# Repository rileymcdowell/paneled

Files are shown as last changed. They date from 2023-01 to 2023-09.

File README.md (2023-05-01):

# The PaneLED Project

PaneLED is an open source hardware, firmware, and software system for managing 
collections of independent RGBW light strips over WiFi via a simple interface.

Features include autodiscovery of new panels via UPnP, group administration 
of like-colored panels, and over-wifi firmware updates.

### Construction Guide 
---

1. [Bill of Materials](/instructions/00_bill_of_materials/README.md)
1. [Circuit Board](/instructions/10_circuit_board/README.md)
1. [Electronics Enclosure](/instructions/20_electronics_enclosure/README.md)
1. [Panel Assembly](/instructions/30_panel_assembly/README.md)
1. [Hanging Hardware](/instructions/40_hanging_hardware/README.md)
1. [Mount Options](/instructions/50_mount_options/README.md)

### Software Development Guide
---

Begin by installing docker and npm

In one terminal, run the following commands to start up the backend.

```bash
./build.sh # Build the docker containers for this project
./up.sh # Start the containers for this project
```

In another terminal, run the following commands to start up the frontend.

```bash
cd frontend
npm install
./start-frontend.sh
```

### License
---

All contents within this repository are released under one of two different licenses. The licenses were chosen to ensure that improvements to this design are shared with the open source community.

All source code is released under the GNU GPL V3.0 license. All remaining resources are released under the CC BY-SA 4.0 license. Below is a mapping of resources to the license
for those resources. 

* GNU GPL V3.0 
    * server source code
    * frontend source code
    * firmware source code
    * docker build and deployment utilities
* CC BY-SA 4.0
    * Enclosure model (lid + box)
    * PCB design
    * Panel frame design
    * Build instructions

The text of both licenses are included in the root of this repository.

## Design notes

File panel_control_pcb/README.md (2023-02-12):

This directory contains a `.f3z` archive that can be loaded into 
Autodesk's Fusion360 to get a complete copy of the PCB design documents
including schematic, board layout, and 3D rendering.

Autodesk offers a free, personal, non-commercial-use version of 
Fusion360, so if that sounds like you and you don't have a philosophical 
objection to the use of nonfree Fusion360 and/or Autodesk just make
an account, download it, and open the `.f3z` file to get access to
everything.

---

In addition, I've copied the individual schematic and board layout files
here for anyone who wishes to use alternative tooling or just get a 
copy of the exported board to order from a PCB prototyping house.

* Board (Gerber) files - `PCB v14_2023-02-12.zip`
* Schematic - `Schematic v10.pdf`

Below are a couple of screenshots you can use to confirm that your tools
have correctly read the source files.

The board layout should look like this:

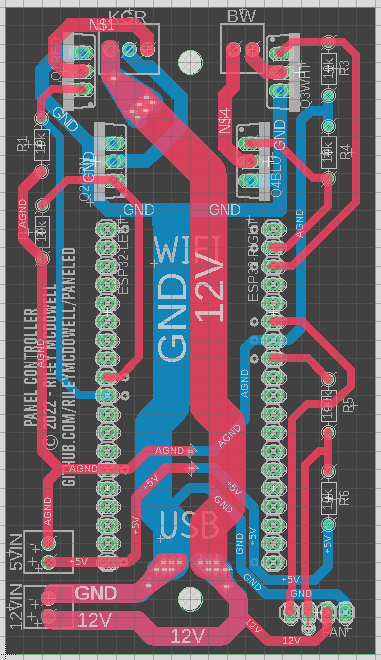
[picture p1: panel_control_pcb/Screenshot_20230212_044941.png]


And the schematic like this:

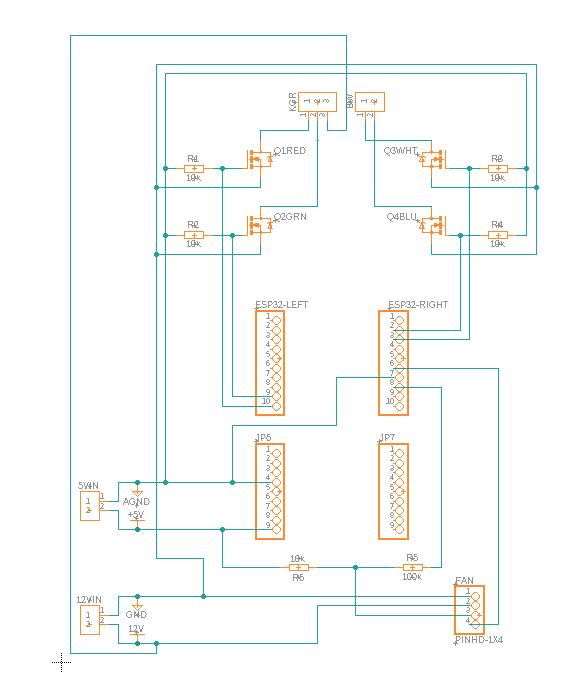
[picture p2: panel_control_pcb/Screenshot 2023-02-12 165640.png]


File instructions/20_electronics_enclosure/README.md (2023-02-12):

# Assembling the Electronics Enclosure

## 3D Printing 

### The Box

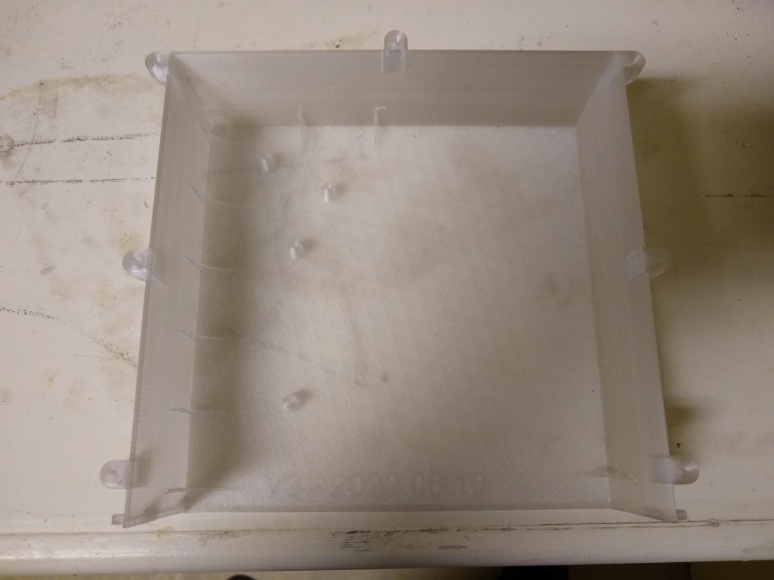
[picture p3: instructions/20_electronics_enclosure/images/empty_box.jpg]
empty box


First, you want to print the box. It's fairly large, about 210mm on each side. It will fit on the build plate
on a 220mm x 220mm 3D printer. I tried a few ways, here's what worked consistently for me:

* Print in Hatchbox brand transparent PETG with an 80&deg; bed and 235&deg; nozzle.
* Scale the model to 101% before printing to allow for thermal contraction to the correct final size after printing.
* Print with part cooling fan speed low, but non zero. I used 25% speed.
* Print on a glass bed inside an enclosure. This limits warping, delamination, and/or loss of bed adhesion.
* Use a 0.6mm diameter nozzle at 0.2mm layer height. With these settings, the box takes about 18 hours to complete.
* Print with an 8mm brim to keep the sharp corners from lifting.
* Use a generous coat of purple glue stick on the bed to ensure good bed adhesion.
* Use a wall line count of 4. This keeps the screw holes surrounded by several lines of solid plastic to tap into.
* Print the initial layer at 15mm/s. I found this helped ensure good adhesion.
* Use 20% infill (triangles). This is of minor importance as most of the box will print solid with these settings.

---
### The Lid

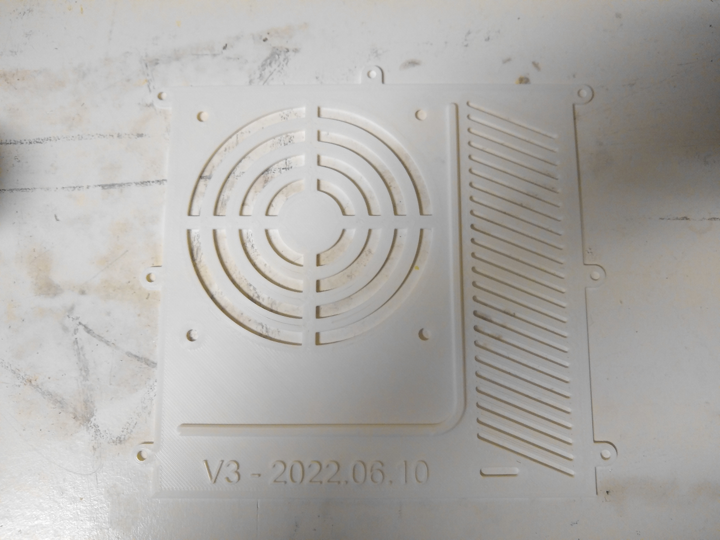
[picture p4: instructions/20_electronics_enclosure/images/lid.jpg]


After you get the box right, print a lid to match. It's roughly the same dimensions, but relatively flat so it will
be less affected by warping due to close proximity to a heated bed. This was easier to get right than the
PETG box, and I found only a subset of those settings was required to get a good result.

* Print in Hatchbox brand white ABS with a 100&deg; bed and 225&deg; nozzle.
* Scale the model to 101% before printing to allow for thermal contraction to the correct final size after printing.
* Print with part cooling fan low but non zero. I used 25% speed.
* Print on a glass bed.
* Print with an 8mm brim to keep the sharp corners from lifting.
* Use a 0.6mm diameter nozzle at 0.2mm layer height. With these settings, each lid takes about 8 hours to complete.
* Use 5 line thick walls - this improves printing speed due to more efficient print head movements.
* Print the initial layer at 15mm/s. I found this helped ensure good adhesion.
* Use 20% infill (triangles). This is of minor importance as most of the box will print solid with these settings.

---
## Tapping Threads

The holes in the box are sized to have threads tapped into them. Due to the depth of the box, it is highly 
recommended to use a small "T" handle tap wrench as shown. I found my double-end adjustable style
hit the walls of the box as I tapped the threads, so I needed to switch to the "T" handle style.

The 7 outer holes of the box are sized to be tapped to M3.5 size. 

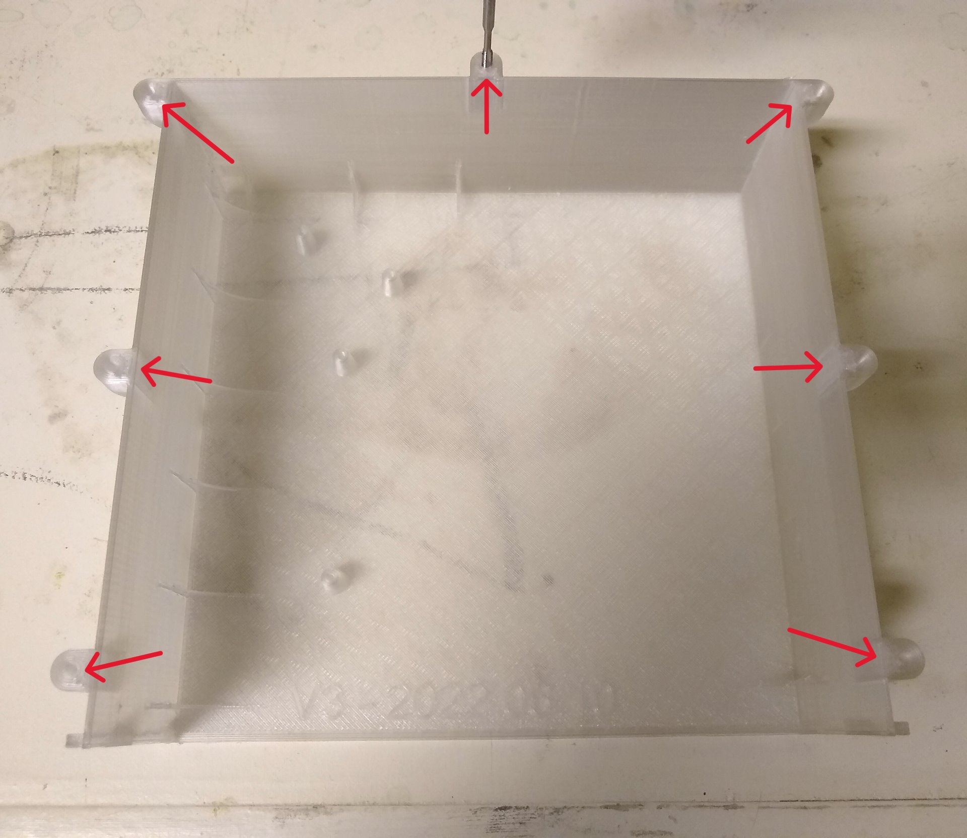
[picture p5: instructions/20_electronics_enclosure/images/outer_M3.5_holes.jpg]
Location of M3.5 holes to tap


The 4 inner holes of the box are sized to be tapped to the slighly smaller M3 size. This
seems to be a common size for PCB mount holes.

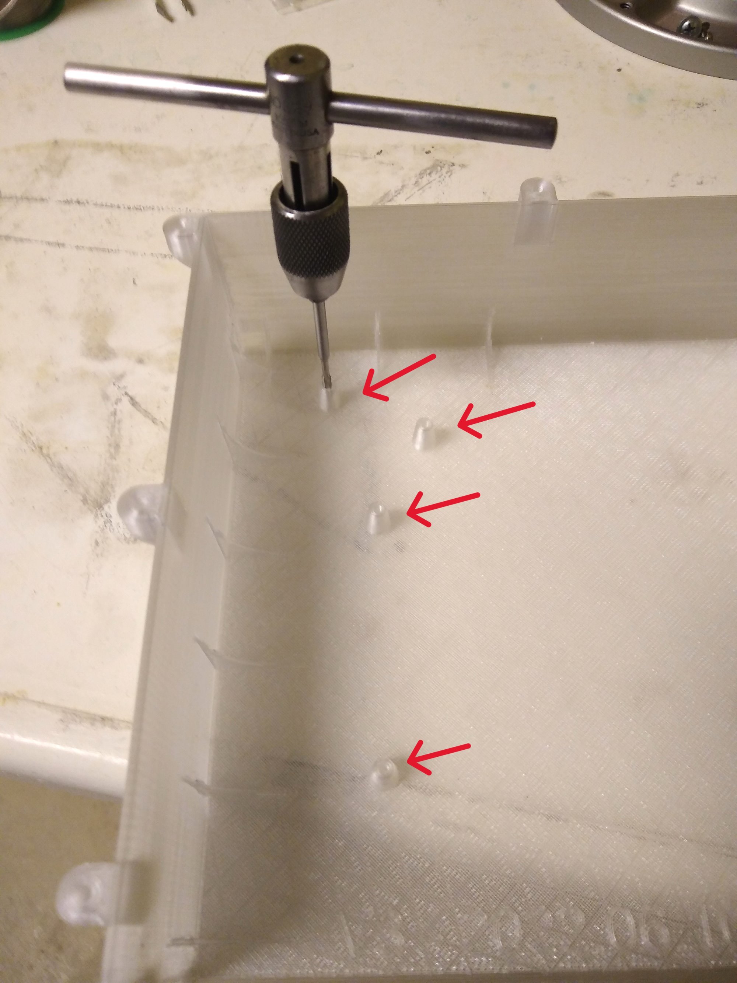
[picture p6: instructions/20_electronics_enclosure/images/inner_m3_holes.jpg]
Location of M3 holes to tap


---

## Assembling the Internals

### Step 0

Verify the power supply is set to the correct voltage for your local mains.

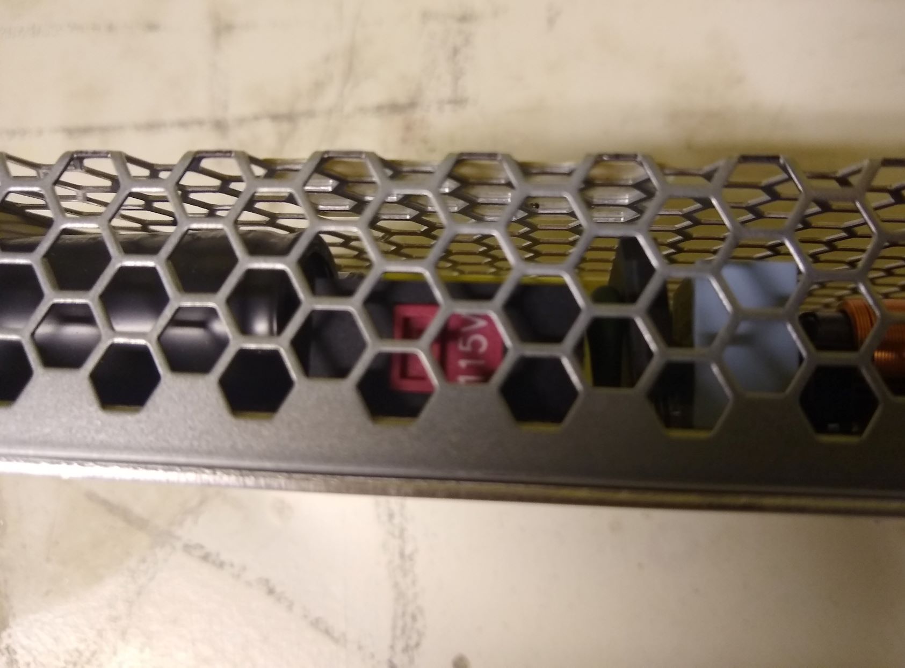
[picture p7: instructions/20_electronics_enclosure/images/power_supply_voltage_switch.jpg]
power supply voltage switch


### Step 1
Begin by putting the 12V Power supply into the box. Attach it with three M3 screws on the right side of the box.

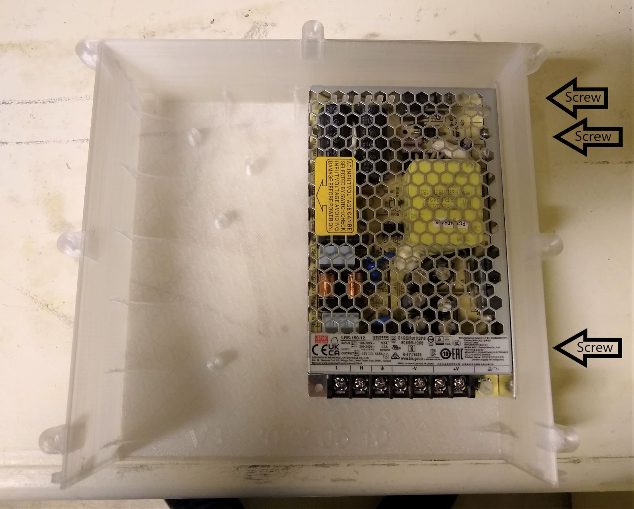
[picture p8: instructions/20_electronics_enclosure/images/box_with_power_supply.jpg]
box with power supply


### Step 2
Next, strip both ends of a pair of wires. I used the following:

* Red / Positive - 21cm (8.25in) of 24AWG stranded wire
* Black / Negative - 20cm (8in) of 24AWG stranded wire

For each wire, strip one end back about 8mm and fix it into the screw terminals 
on the power supply, red should go to `+V` and black to `-V`. Strip the other end about 4mm and leave them for the next step.
It should look like this.

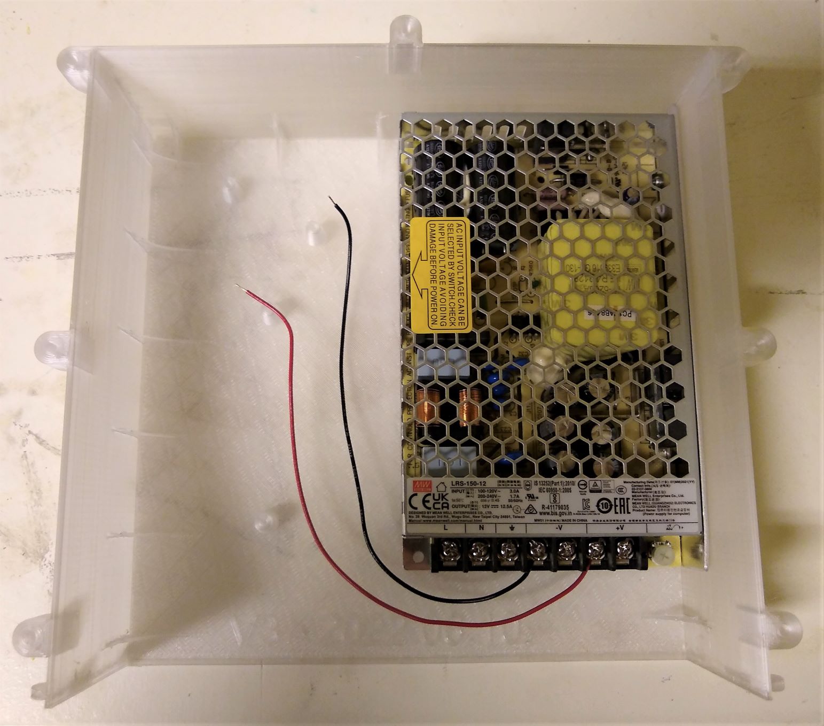
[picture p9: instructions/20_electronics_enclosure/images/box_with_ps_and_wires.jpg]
box with power supply and wires


### Step 3
Next we need to adjust a buck converter to buck down to 5V from the factory set voltage. 
Use a voltage source like a bench power supply or 9V battery to produce a voltage 
somewhat greater than the 5V required by the ESP32 dev board. Connect it to the 
`+in` and `-in` solder terminals on the buck converter. Then use a digital 
multimeter to read the voltage on the output terminals. Turn counterclockwise 
until the voltage is bucked down to 5V. **Note**: many buck converters come 
pre-set to a voltage many times higher than 5V. You will need to apply 
a **large number** of counterclockwise turns before you will see a noticable 
bucking effect on voltage.

I suggest adjusting to within 5.00&#xb1;0.05V.

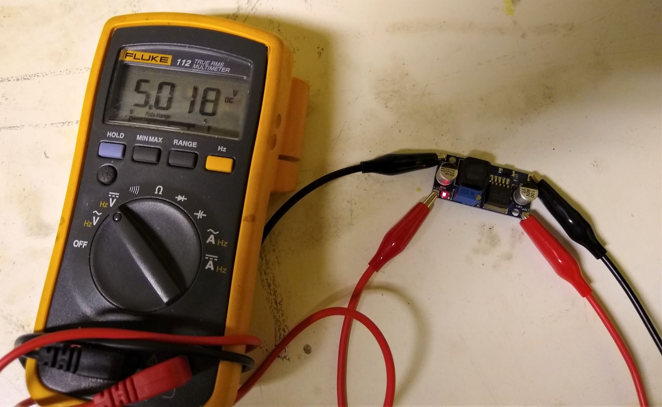
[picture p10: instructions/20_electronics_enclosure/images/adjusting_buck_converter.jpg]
adjusing buck converter


### Step 4
Solder the `+in` terminal of the buck converter to the red wire, and the `-in` terminal
to the black wire. This can be done most easily using "helping hands" type
soldering aids to hold the wires and converter in position over the box
while soldering. I recommend investing in a Panavise 350 and "Third Hand"
PanaHand add-on or similar to make this and all your future soldering projects easier.

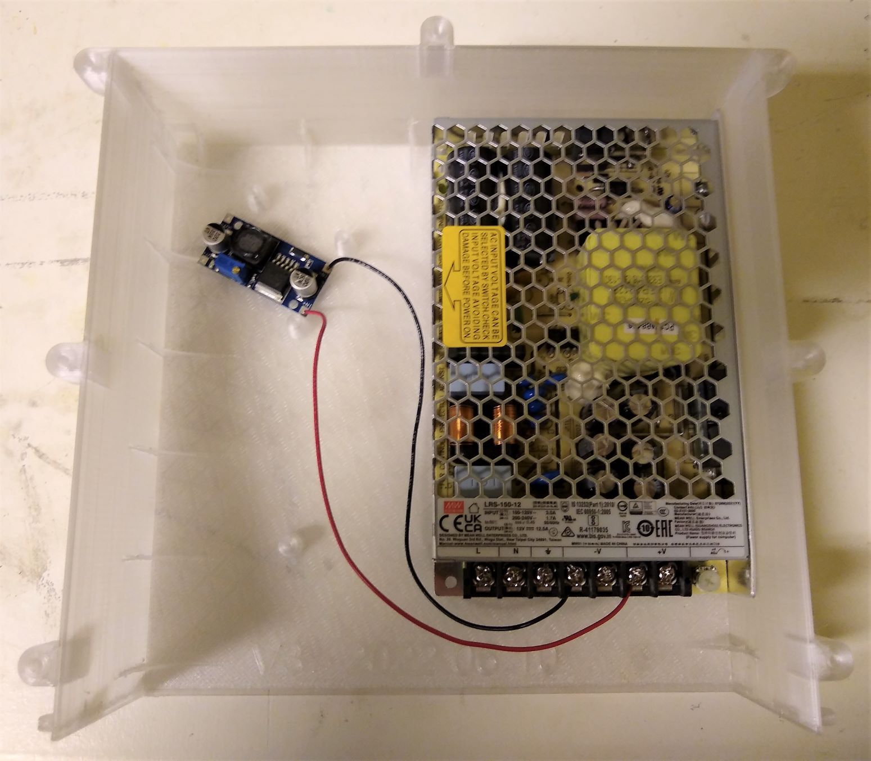
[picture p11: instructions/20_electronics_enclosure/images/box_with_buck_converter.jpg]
box with buck converter


### Step 5
Next, solder wire leads to the lower voltage side of the buck converter. I
used the following:

* Red / Positive - 11.5cm (4.5in) of 24AWG stranded wire
* Black / Negative - 14cm (5.5in) of 24AWG stranded wire

I stripped both ends of the wires back about 4mm, and soldered one end to
the buck converter. When you're done, you can turn your soldering iron back off. 
It's screw terminals and screwdrivers for a while now.

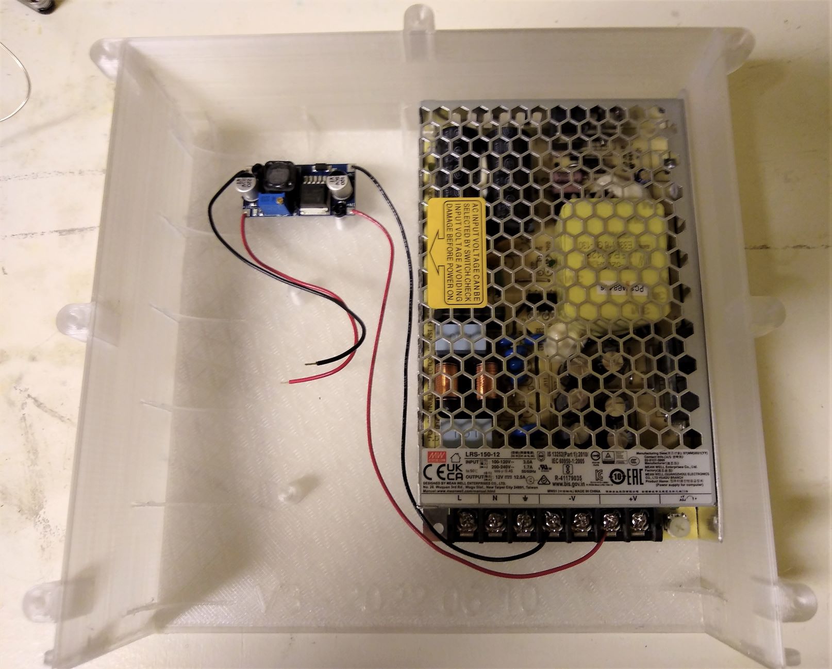
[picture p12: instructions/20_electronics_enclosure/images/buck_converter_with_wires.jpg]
buck converter with wires


### Step 6
Now go ahead and fasten the buck converter and soldered PCB with four M3 screws
to the tapped holes in the box using two screws each. Screw down the red and black wires
from the buck converter into the 5V input terminal on the PCB as shown
in the photo below. Take care to use the lower 5V terminal rather than the upper 12V
terminal, and to use the correct polarity (red above black).

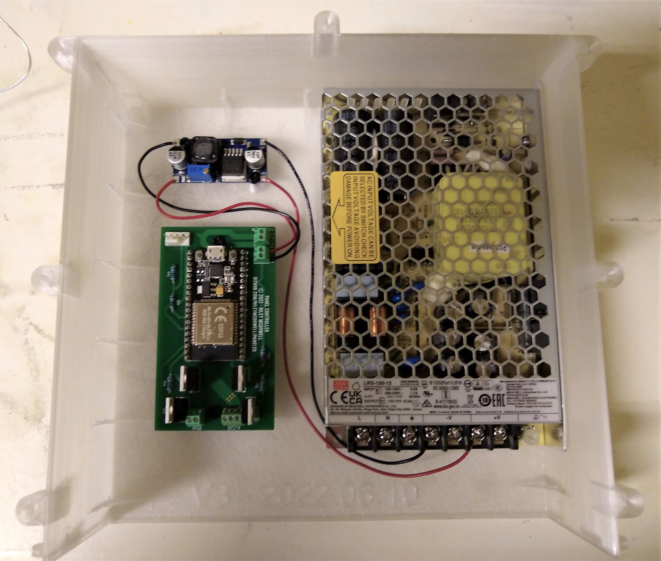
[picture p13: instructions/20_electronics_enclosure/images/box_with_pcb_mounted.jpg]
box with pcb mounted


### Step 7
Next add in the 12V supply wires. These wires need to be able to carry the 
full current of the LED strip at maximum brightness for an indefinite period. 
For that reason, I used slightly different wires with higher current capacity
for this application.

* Red / Positive - 20cm (8in) of 22AWG solid copper wire
* Black / Negative - 18cm (7.25in) of 22AWG solid copper wire

<small><small>**Note**: 22AWG solid copper wire is rated for 7A of current in chassis wiring 
applications. In practice I have observed less than 50W power draw
for the panel at maximum brightness on all channels. 50W at 12V is about
4.2A, so this should be appropriately spec'd.</small></small>

Because these wires carry non-negligible current, be sure you are tightening
the screw terminals down securely. You will want to use high quality
precision screwdrivers to ensure a good, low resistance clamping connection. 

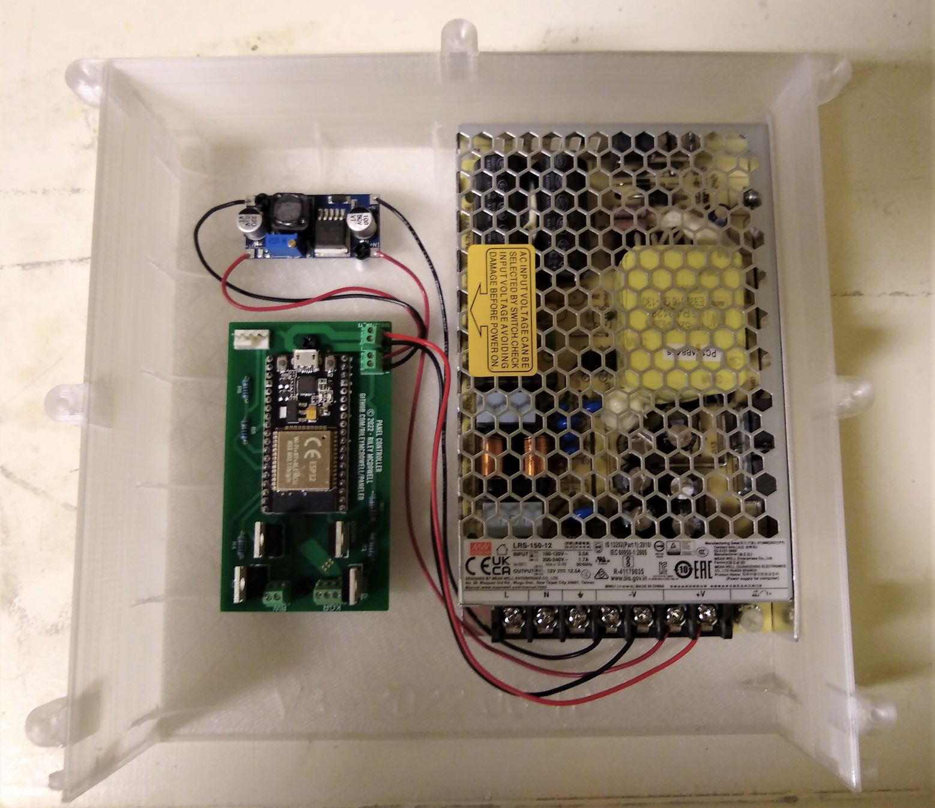
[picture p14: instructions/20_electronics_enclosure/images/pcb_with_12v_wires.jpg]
pcb with 12V wires


### Step 8

The 5050 LED kit I used came with a 5 conductor wiring plug, so I incorporated
it directly into this design. The 2+3 screw terminals line up with the WBRGK
wires, so clamp them down as well. Like before, use precision screwdrivers
to ensure secure, low resistance termination of the wires. Pay special 
attention to the black (labeled `k`) wire, as this is the 12V input 
for the strand and carries the full current of the entire light strip.
Get it nice and tight.

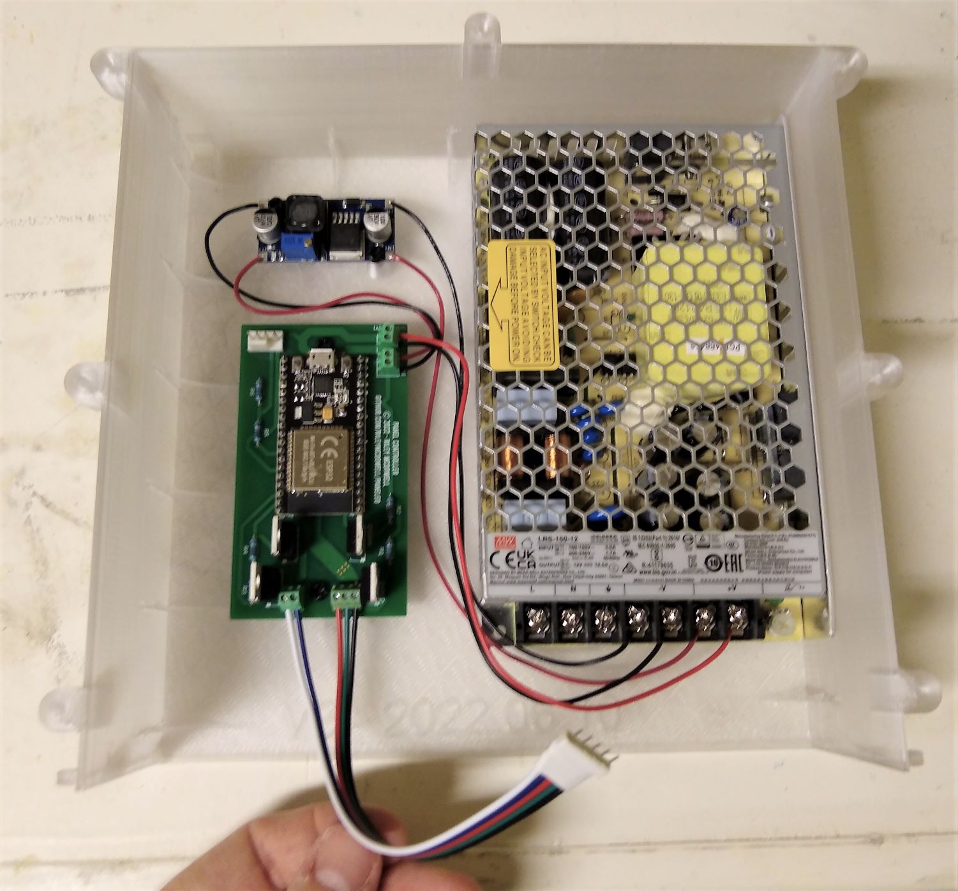
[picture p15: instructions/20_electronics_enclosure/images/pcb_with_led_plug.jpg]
pcb with led plug


### Step 9

Fire up your soldering iron again, it's time to solder the IEC-320 C14 fused socket.
The correct wiring is shown below. These wires need not be any larger capacity than
the wires for the LED strip. I had some nice colors of silicone insulated wires
around, so I used them.

* Red / Line / L - 22AWG silicone insulated stranded wire
  * 9cm (3.5in)
  * 3cm (1in)
* Yellow / Neutral / N - 22AWG silicone insulated stranded wire
  * 9cm (3.5in)
  * 4.5cm (1.75in)
* Green / Ground / &#9178; - 22AWG silicone insulated stranded wire
  * 9cm (3.5in)

It takes considerable heat to get the terminals hot enough to solder,
so don't hesitate to crank your iron temperature up (say 275C) and hold it 
on the terminal for a bit to let a generous portion of solder flow 
into the hole in the terminal as well as between the strands of 
your wire. That worked for me even using lead-free solder.

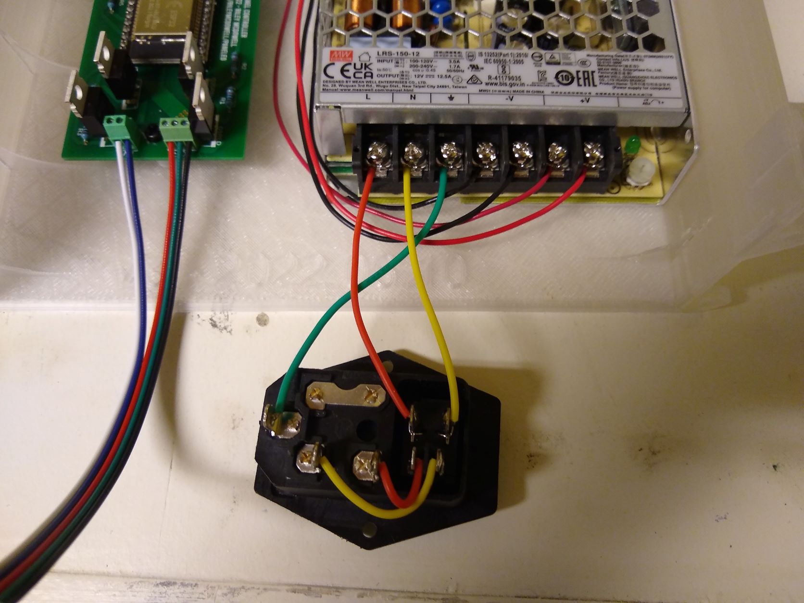
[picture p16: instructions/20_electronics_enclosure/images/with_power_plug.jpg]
with power plug


If you choose to add a 120mm cooling fan, get it out and 
rotate it as shown, with the wires oriented near the bottom
right.

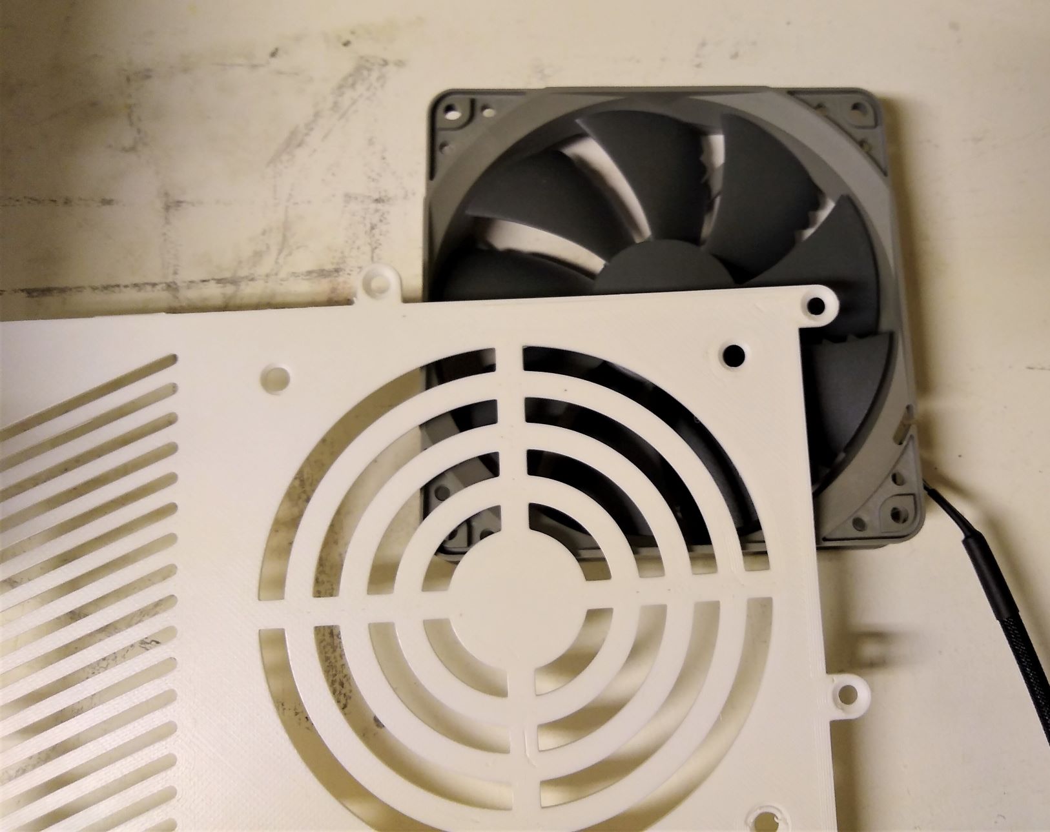
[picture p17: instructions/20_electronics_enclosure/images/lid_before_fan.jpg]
lid before fan


Make sure the fan is set to blow air _into_ the enclosure. The arrow
indicating airflow direction should point down, away from the lid.

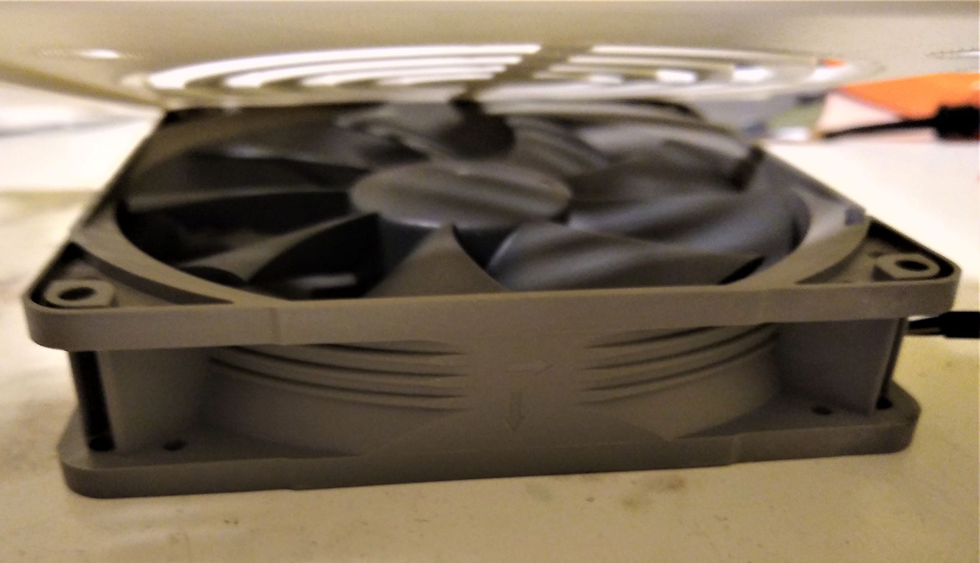
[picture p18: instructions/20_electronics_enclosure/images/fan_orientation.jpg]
fan orientation


When you have the fan cable and fan airflow direction set, use the self-tapping
screws provided with the fan to screw it into the lid as shown.

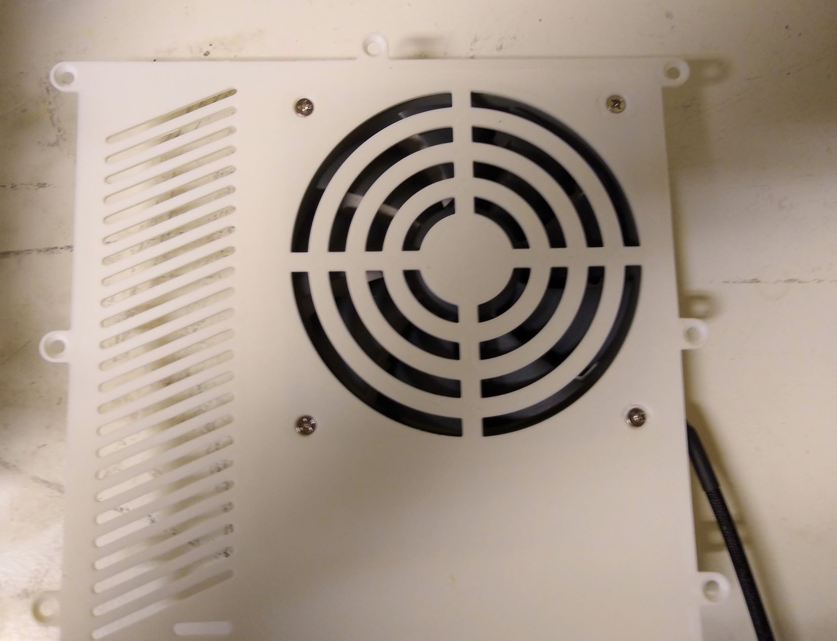
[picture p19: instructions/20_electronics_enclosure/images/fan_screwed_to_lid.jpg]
fan screwed to lid


Connect the fan header to the main PCB.

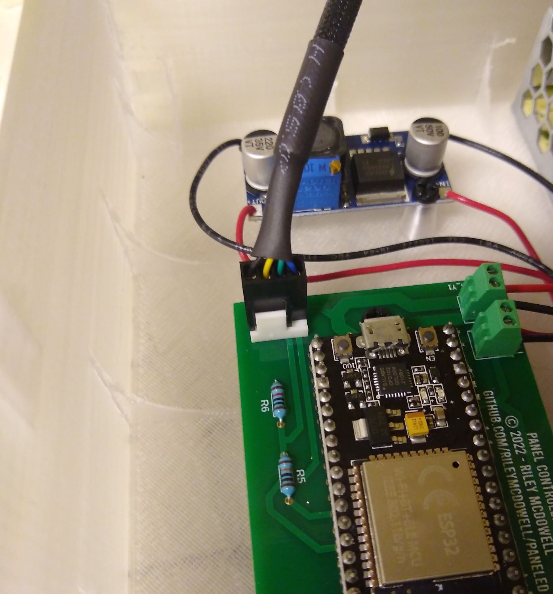
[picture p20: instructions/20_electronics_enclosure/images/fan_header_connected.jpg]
fan header connected


Use 7 M3.5 screws to attach the lid (with attached fan to the main enclosure box).
The placement of the fan cable is tricky. You want to trap the cable around
the sides of the fan, between the fan frame and the box walls. Be sure it doesn't 
end up trapped underneath the fan blades where it could interfere with the fan.
You also don't want to strain the cable where it leaves the fan or where the
header plugs into the PCB. It's not hard, but it does require careful alignment
while the lid is screwed on.

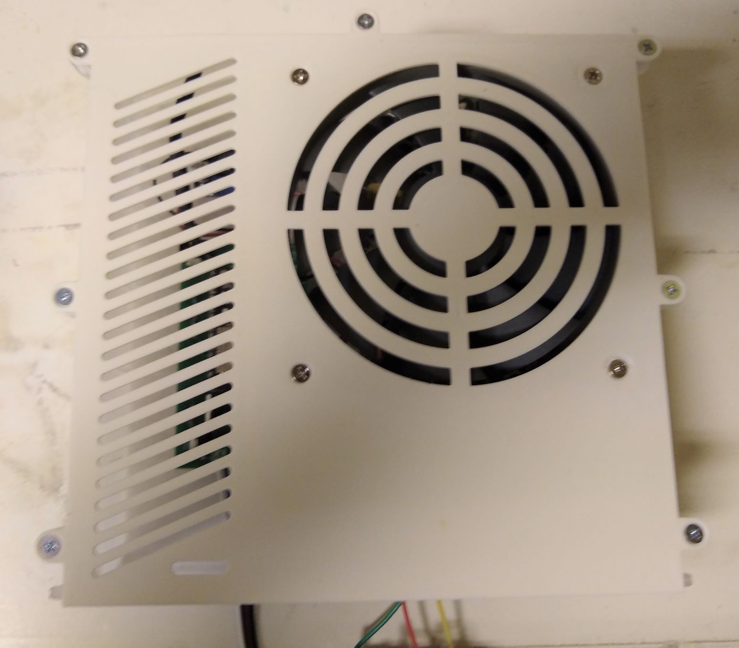
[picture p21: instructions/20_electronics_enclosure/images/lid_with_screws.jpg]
lid with screws


Last, fish the LED wire harness through the small slot in the bottom of the lid. 

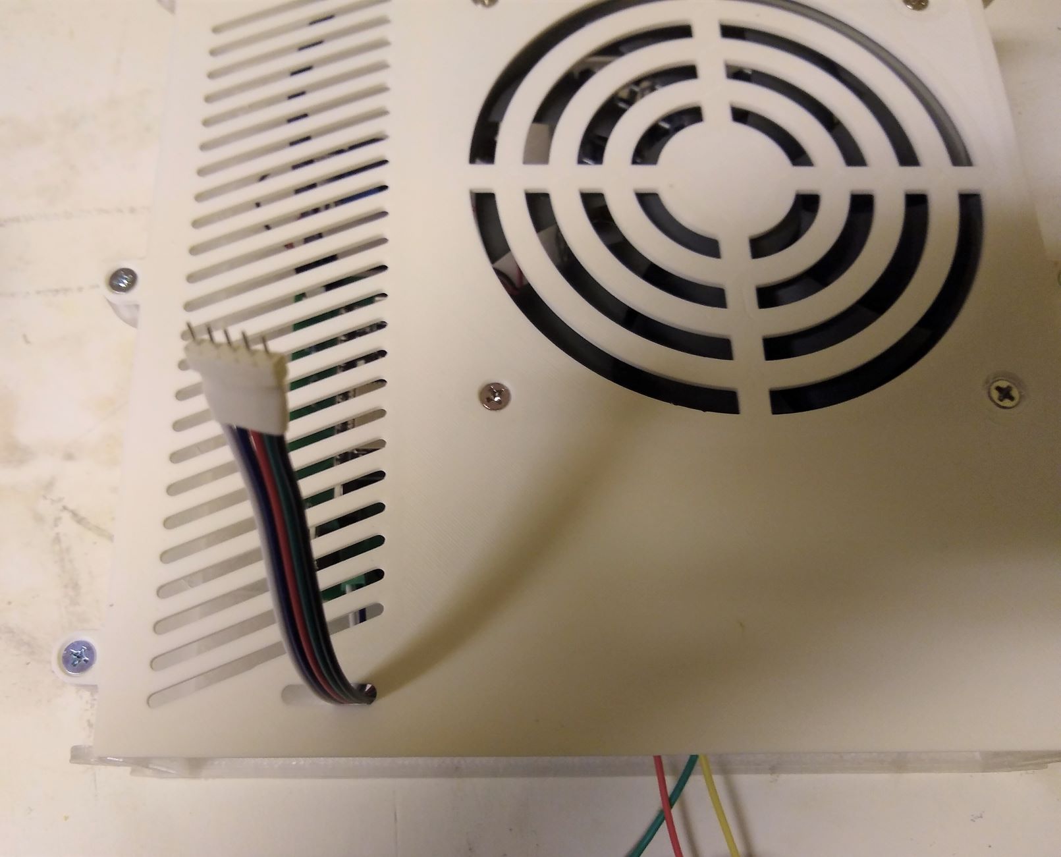
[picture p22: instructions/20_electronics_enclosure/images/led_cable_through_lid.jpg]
led cable through lid


## _**Congratulations!**_ 

Your electronics enclosure is now assembled!

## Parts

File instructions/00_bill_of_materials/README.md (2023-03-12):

# The Bill of Materials

Below is a bill of materials required to build a 
complete PaneLED panel including lights an electronics.

You may want additional unlighted panels if you are 
acoustically treating a room. For that reason, the 
BoM has been divided into "construction materials"
and an "additional lighting materials". The lighting
materials are only required if you add lighting to 
the panels.

---
## Construction Materials

| Item | Cost | Unit | # of Panels | Cost/Panel | Vendor | Details | Link |
|:-----|-----:|:-----:|---|---:|---|---|---|
| Rockwool Insulation | $104.99 | Package | 8 | $13.13 | Do it Best Hardware | 24" x 47" size | [Link](https://www.doitbest.com/shop/building-materials/insulation-and-house-wrap/insulation/stone-wool-insulation/rockwool-safe-n-sound-r-15-24-in-x-47-in-stone-wool-insul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) |
| Pine Board | $4.99 | 8' Board | 2/3 | $7.49 | Menards | 1"x4"x8' "quality" pine | [Link](https://www.menards.com/main/building-materials/lumber-boards/boards/1-x-4-quality-pine-board/1033432/p-1444421996260-c-13115.htm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) |
| Construction Screws | $6.22 | 158/lb | 19.75 | $0.31 | Menards | #8 1 3/4" torx head screws. Use 2 per corner, 8 per panel | [Link](https://www.menards.com/main/hardware/fasteners-connectors/screws/wood-screws/midwest-fastener-reg-8-x-1-3-4-star-drive-yellow-zinc-flat-head-wood-screw-158-count/09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) |
| Wood Screws | $4.53 | Box of 175 | 7.9 | $0.57 | Menards | #6 x 3/4" wood screws. Need 22 per panel | [Link](https://www.menards.com/main/hardware/fasteners-connectors/screws/wood-screws/midwest-fastener-reg-8-x-1-3-4-star-drive-yellow-zinc-flat-head-wood-screw-158-count/09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) |
| Staples | $3.51 | Box of 1250 | 30 | $0.12 | Menards | 1/4" T50 Staples. Use 3-4 per foot of fabric | [Link](https://www.menards.com/main/tools/hand-tools/staplers-staples-rivet-tools/arrow-reg-t50-reg-1-4-leg-x-3-8-crown-galvanized-heavy-duty-staples-1-250-count/50424sp/p-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) |
| Rear Fabric | $3.99 | Per Yard | ~1 | $3.99 | JOANN Fabric | Cheap, thin, breathable | [Link](https://www.joann.com/utility-fabric-upholstery-underlining/10173300.html) |
| Front Fabric | $26.99 | Precut Piece | 1 | $26.99 | Amazon | 100 x 146cm | [Link](https://www.amazon.com/gp/product/B09LXLGHHF) |
| Corks | $8.79 | 30 Corks | 15 | $0.59 | Amazon | #8 Straight 7/8" x 1 3/4" | [Link](https://www.amazon.com/gp/product/B0B4ZXD5L3) |
| PLA Filament | $24.99 | 1KG Spool | 15 | $1.64 | Amazon | Hatchbox True Black PLA | [Link](https://www.amazon.com/gp/product/B00J0ECR5I) |
| **Total** | | | 1 | $54.26 | | Single panel cost | |

In summary, you're looking at about $60/panel if you don't include lights. You could cut that cost down significantly by choosing more thrifty fabric to wrap the front and sides. Whatever fabric you choose should be very breathable. You want air, and thus sound, to pass through the fabric and into the rockwool insulation inside.

---
## Electronics Materials

| Item | Cost | Unit | # of Panels | Cost/Panel | Vendor | Details | Link |
|:-----|-----:|:-----:|---|---:|---|---|---|
| WRGB LED Strip | $23.99 | Each | 1 | $23.99 | Amazon | 5m Cool White; IP30; 12mm | [Link](https://www.amazon.com/gp/product/B01D1I4XBY) |
| ESP32 Dev Kit | $13.99 | 2 Pack | 2 | $6.99 | Amazon | KeeYees 38PIN; Narrow Version | [Link](https://www.amazon.com/gp/product/B07QCP2451) |
| 12V Power Supply | $27.60 | Each | 1 | $27.60 | Amazon | Meanwell 12V 12.5A; Passive Cooled | [Link](https://www.amazon.com/gp/product/B00M8TBJLK)
| Buck Converter | $16.99 | 10 Pack | 10 | $1.70 | Amazon | DC/DC 3A Buck Only | [Link](https://www.amazon.com/gp/product/B07VVXF7YX) |
| MOSFETs | $7.99 | 10 Pack | 2.5 | $3.20 | Amazon | RFP30N06LE 30A 60V N-Channel Logic-Level | [Link](https://www.amazon.com/gp/product/B07CTF1JVD) |
| C14 Fused Panel Plug | $10.49 | 3 Pack | 3 | $3.49 | Amazon | Includes 10A Fuse | [Link](https://www.amazon.com/gp/product/B082ZFRV1B) |
| Cooling Fan | $14.99 | Each | 1 | $14.99 | Amazon | Noctua Redux NF-P12 PWM 1700RPM | [Link](https://www.amazon.com/gp/product/B07CG2PGY6) |
| M3 Screws | $6.99 | 60 Pack | 8.5 | $0.83 | Amazon | M3 x 6mm; 7 per panel | [Link](https://www.amazon.com/gp/product/B012TE12CY) |
| M3.5 | $3.14 | 100 Pack | 14 | $0.23 | Amazon | M3.5-0.6 x 6mm flat, cone head | [Link](https://www.amazon.com/gp/product/B00137MU5C) |
| 2 x 2.54mm Screw Terminal | $1.77 | Each | 1/3 | $5.31 | DigiKey | Molex Part# 039773002 | [Link](https://www.digikey.com/short/mvt4n27q) |
| 3 x 2.54mm Screw Terminal | $1.55 | Each | 1 | $1.55 | DigiKey | Wurth Elektronik Part# 691210910003 | [Link](https://www.digikey.com/short/mtrbfvpd) |
| 4-pin fan header | $0.56 | Each | 1 | $0.56 | DigiKey | Molex Part# 0470531000 | [Link](https://www.digikey.com/short/d5n8d2tj) |
| 10k Ohm Resistor | $4.99 | 100 Pack | 20 | $0.25 | Amazon | 1/4W metal film; 1% Tolerance | [Link](https://www.amazon.com/gp/product/B08QRJZ82J) |
| 100k Ohm Resistor | $4.99 | 100 Pack | 100 | $0.05 | Amazon | 1/4W metal film; 1% Tolerance | [Link](https://www.amazon.com/gp/product/B08QRSQB18) |
| PETG Filament | $21.99 | 1kg Spool | 4 | $5.50 | Amazon | PETG has good temp stability | [Link](https://www.amazon.com/gp/product/B07PFS4J97) |
| Custom PCB | $2.50 | Each | 1 | $2.50 | JLCPCB | With ENIG finish | [Instructions](../10_circuit_board/README.md) |
| **Total** | | | 1 | $98.74 | | Single panel Cost | |

In total, you're adding about $100/panel to include all the extras needed for lighting. 
A few notes about these materials:

* The ESP32 dev kits must be the 38 pin narrow version to fit the PCB design
  for this project. Unfortunately, this version is not the most common version
  available. The specific model you want is identifiable py the 19-pin 
  headers down the complete length of each side of the dev board, and no mounting 
  holes present of any kind. Compare with the assembly instruction photos before you buy.
* Don't be tempted by power supplies from other brands - reliability is often an issue 
  with knockoffs.
* Don't be tempted to order knockoff screw terminals and fan headers. You want 
  ones made of nylon to withstand the temperatures needed to solder, and cheap 
  knockoffs are sometimes made of other, cheaper plastics like ABS that melt
  when soldered.
* The 1% tolerance resistors are overkill in their precision, but so cheap you 
  might as well get them!

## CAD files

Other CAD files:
panel_control_pcb/LED Controller Board v12.f3z

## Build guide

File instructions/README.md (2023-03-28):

# PaneLED Project

Want to build your own Paneled project? Follow the instructions below.

1. Consult the [Bill of Materials](/instructions/00_bill_of_materials/README.md) and order the parts.
2. Order the [Custom PCB](/instructions/10_circuit_board/README.md) and solder it up.
3. 3D print the [Electronics Enclosure](/instructions/20_electronics_enclosure/README.md), and wire it up.
4. Build the [Panel Itself](/instructions/30_panel_assembly/README.md) with good old fashioned wood, nails, insulation, and cloth.
5. 3D print the [Hanger Hardware](/instructions/40_hanging_hardware/README.md).
6. Consult the [Mount Options](/instructions/50_mount_options/README.md) to decide how to hang your panel[s].

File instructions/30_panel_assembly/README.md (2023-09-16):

# Assembling the Panel

## Preparing the Boards

The wooden frame must be precisely sized to snugly hold the rockwool insulation 
inside by friction alone. The insulation is sized to work with United States 
customary units (inches) and the guide to the frame adopts the same conventional 
units. 

The insulation itself is sized so that two pieces stacked
vertically will friction fit between 24 inch on-center wall framing 
in an 8 foot tall wall framed with 2" x 4" lumber. To save on cost and 
weight, we'll use 1" x 4" pine boards but achieve an identical friction
fit. To do so, you'll want to cut the following pieces.

* 2 x 24 inch lengths of 1" x 4" lumber
* 2 x 47 inch lengths of 1" x 4" lumber

## Routing the Switch Plate 

One of the two 24 inch boards will need a hole routed out to allow the switch to pass through
between the outside and inside of the box. To do so, begin by tracing an outline of the 
switch onto the board.

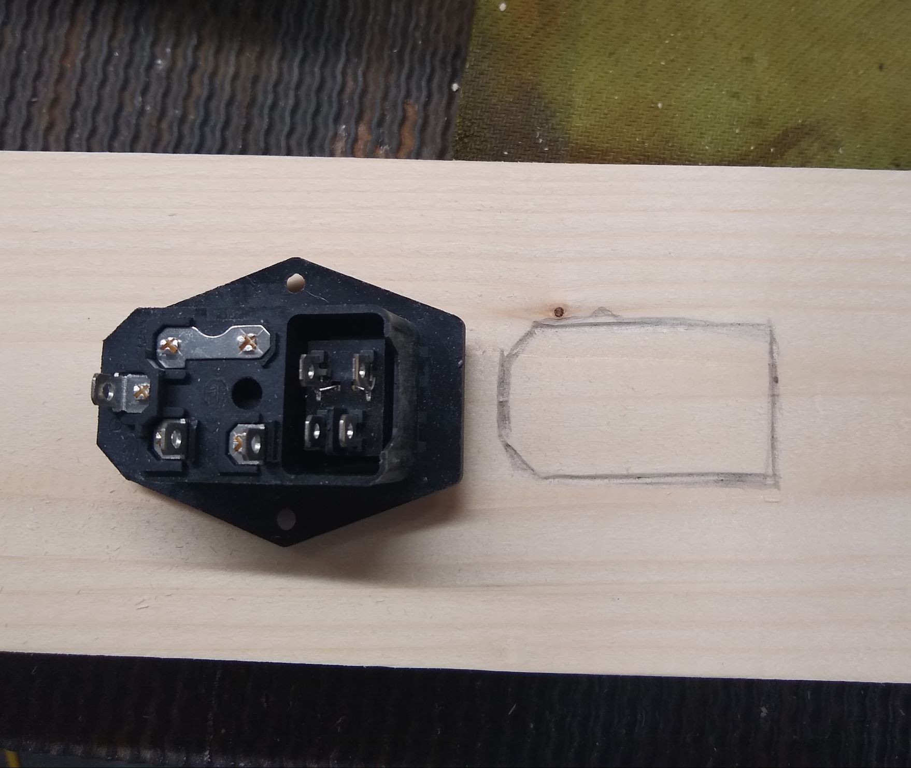
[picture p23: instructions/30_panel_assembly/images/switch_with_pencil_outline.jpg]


When you are satisfied with your outline, drill a hole large enough to fit a router bit.
I chose to route the holes using a dremel with router attachement in a dremel
drill press, so a small hole was sufficient.

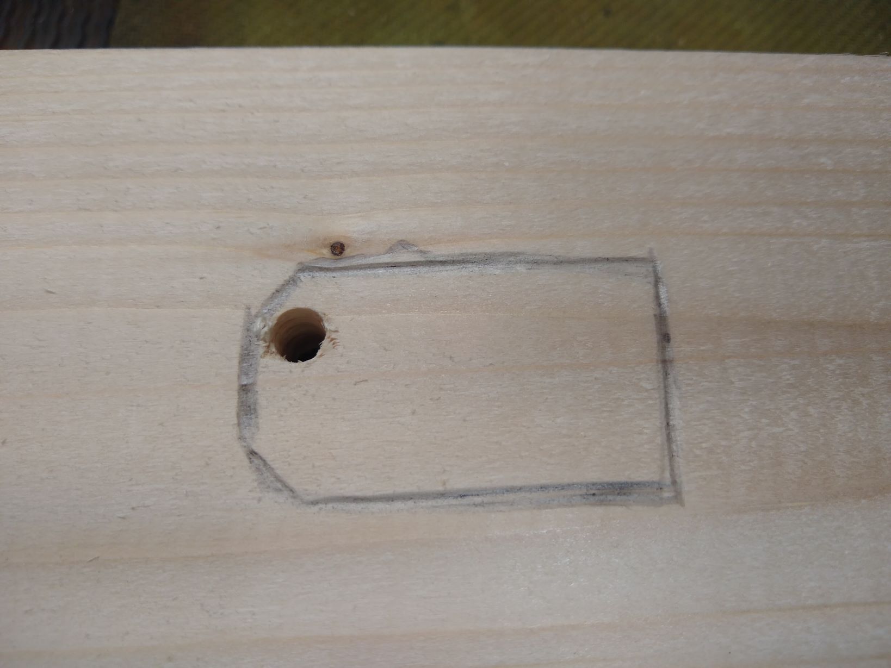
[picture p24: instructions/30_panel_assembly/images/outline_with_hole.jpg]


Fire up the dremel router and route out the hole. Even with pine, I had
to go very slow to avoid overheating the bit.

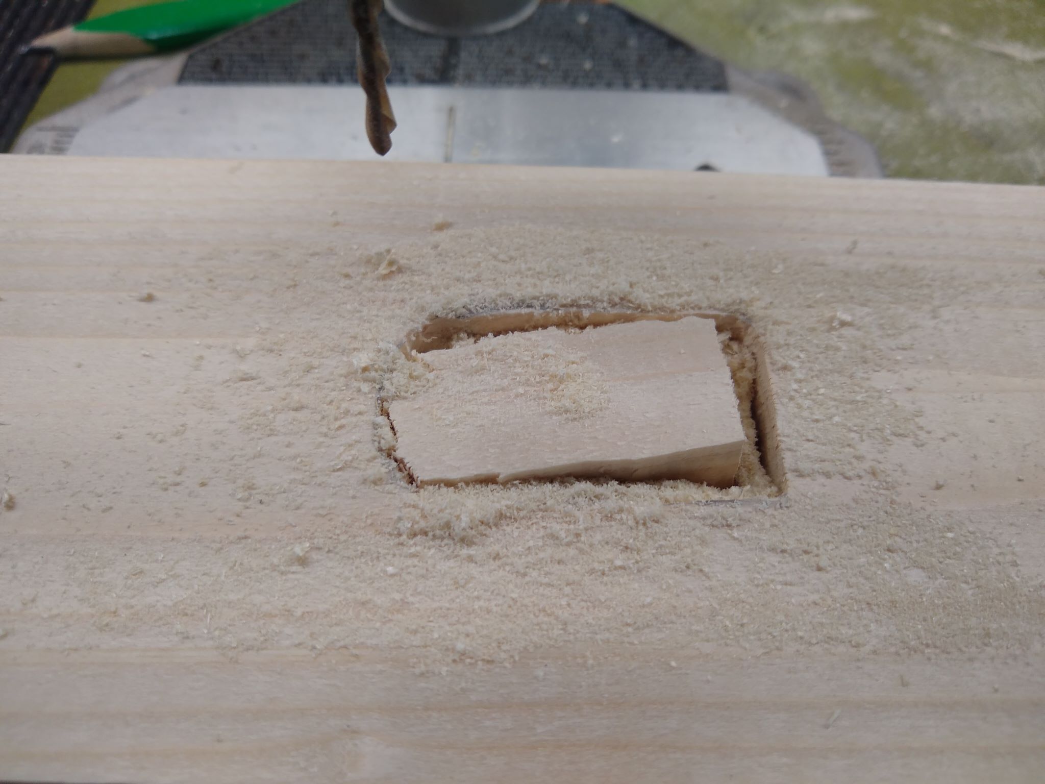
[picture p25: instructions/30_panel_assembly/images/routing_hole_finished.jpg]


My holes usually came out too small, so I would finish them with a file
to make them slightly oversized.

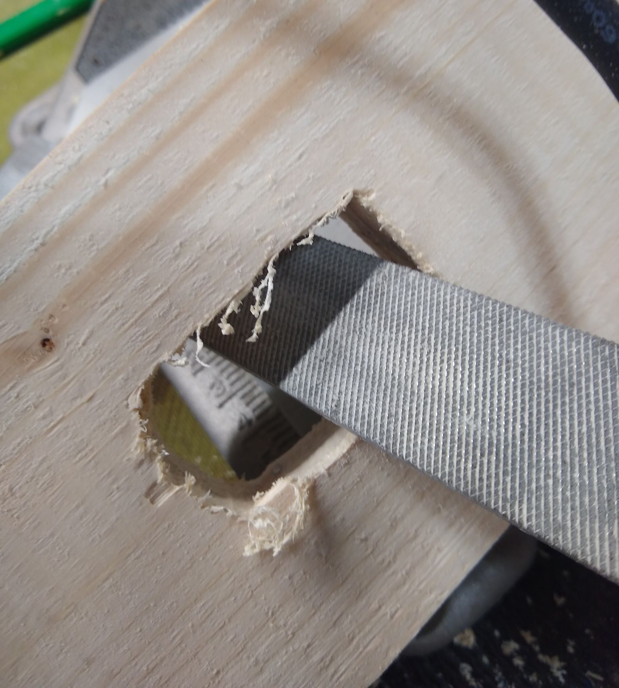
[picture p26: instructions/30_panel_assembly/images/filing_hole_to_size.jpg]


This is how it should look when you're done. There should be some
slop/play in the hole. You'll be tucking fabric along all four sides
of the switch, so don't worry if your hole ends up a little too big.

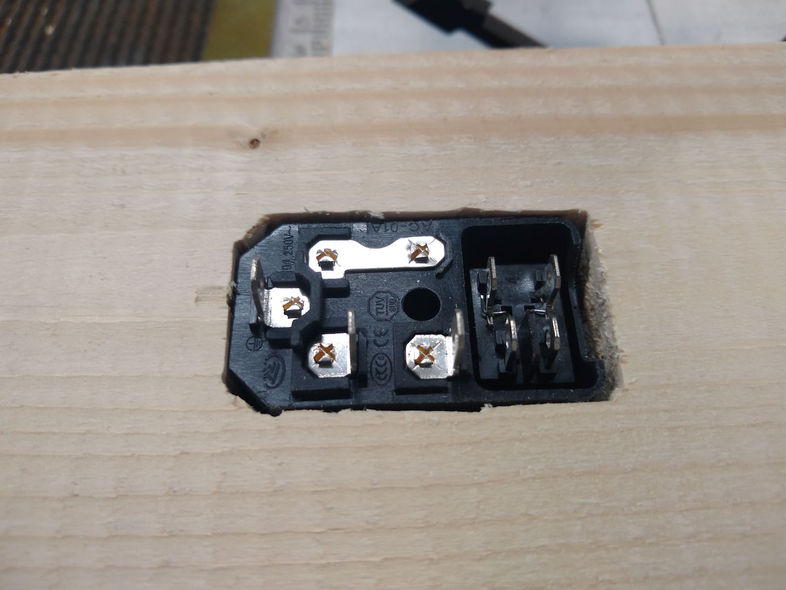
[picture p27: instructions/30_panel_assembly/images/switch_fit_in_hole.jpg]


Later on in construction, I learned that the pine is quite soft and the
construction screws self-tap easily, even through the fabric.
Drilling pilot holes is entirely optional. Note the small holes in
the top and bottom of the switch in this image.

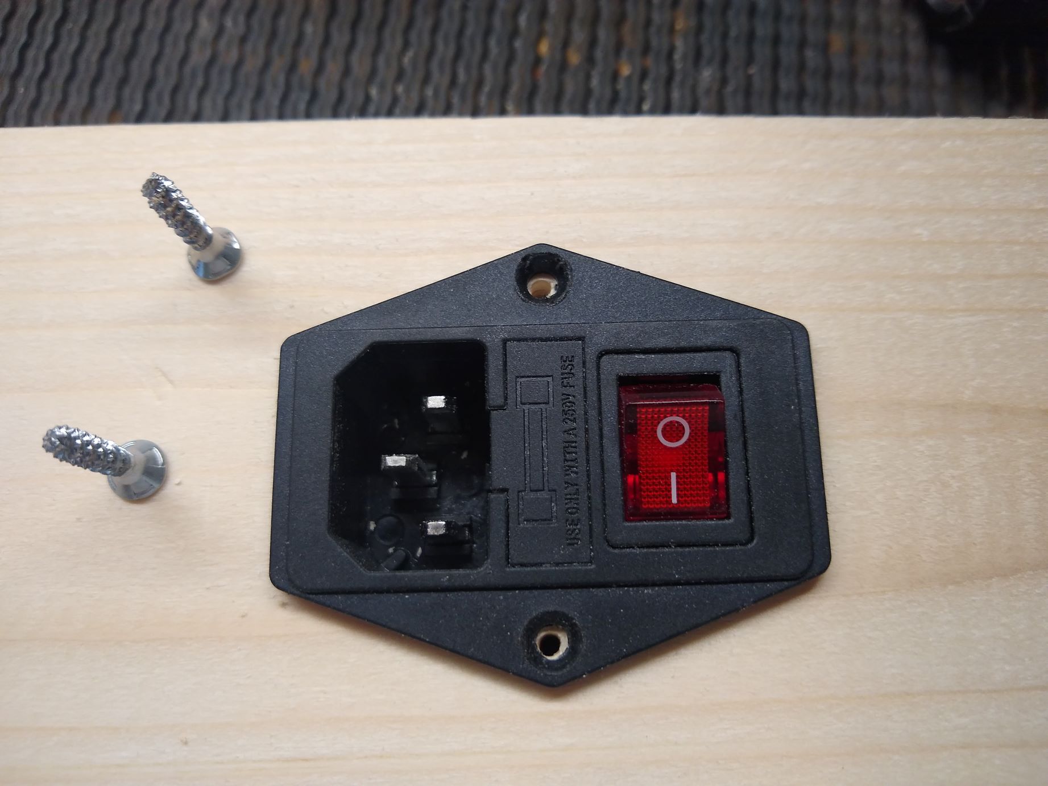
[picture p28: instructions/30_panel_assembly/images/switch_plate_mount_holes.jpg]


When you're done, one of the two 24 inch boards should be ready to mount
a switch.

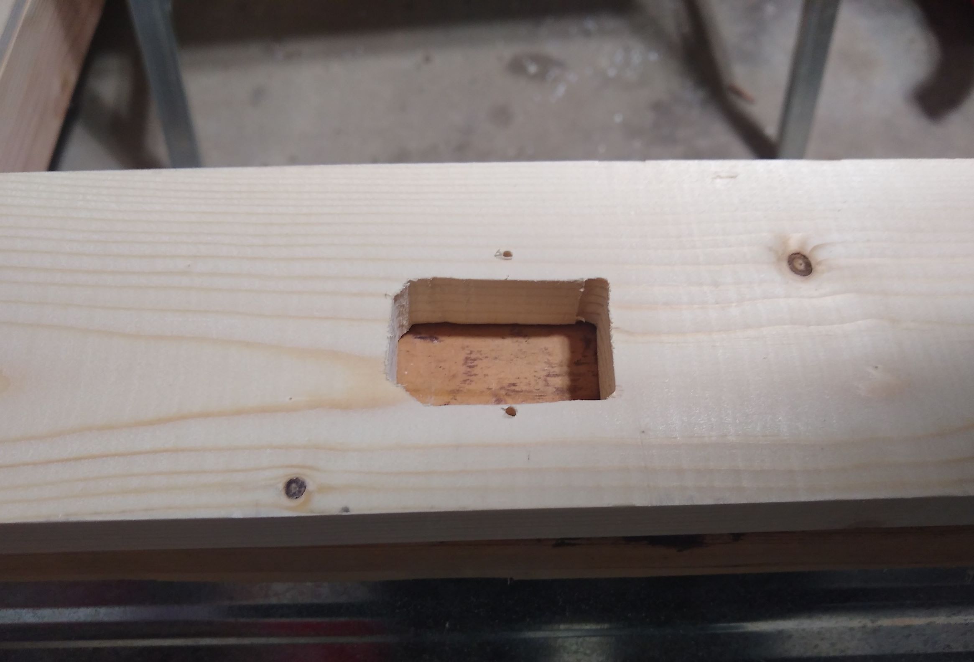
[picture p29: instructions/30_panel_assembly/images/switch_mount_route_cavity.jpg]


## The Wooden Frame

The 24 inch pieces are the top/bottom of the frame, with the 47 inch pieces
sandwiched in between. Nominal 1" x 4" pine boards have an actual thickness of 
3/4 inch, so the center area should measure exactly 47 inches by 22 1/2 inches.
Rockwool is intended to fit this sized space.

The following ASCII art illustrates the correct layout.

```
-------------------------
|        24 inch        |
-------------------------
|    |             |    |
|    |             |    |
|    |             |    |
|    |             |    |
|    |   22 1/2"   |    |
| 47 |      x      | 47 |
|inch|     47"     |inch|
|    |             |    |
|    |             |    |
|    |             |    |
|    |             |    |
-------------------------
|        24 inch        |
-------------------------
```

In each corner, drill two holes through the 24 inch board into the 47 inch board
sized to accomodate a #8 1-3/4 inch construction screw. A 1/8" drill bit
is a good size for most #8 screws, and 2 inch hole depth is sufficient. 
After drilling the hole, use a countersink bit to create a
conical cavity to recess the construction screw head. Finally,
install the construction screw. The hole should look as shown 
below (with one screw installed and one about to be installed).

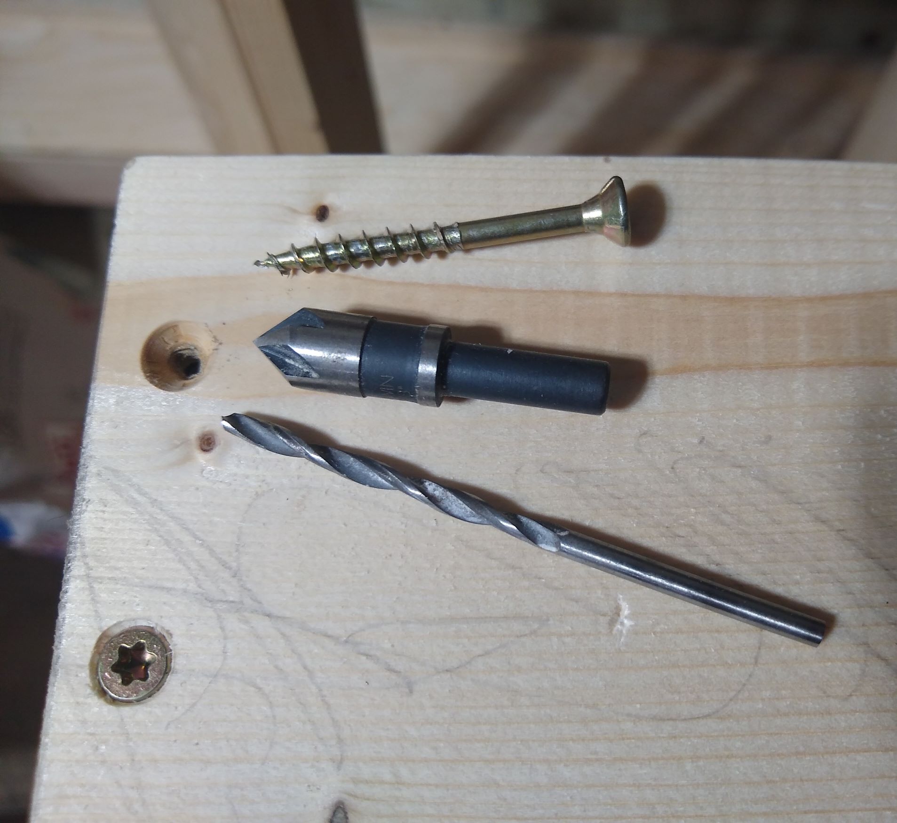
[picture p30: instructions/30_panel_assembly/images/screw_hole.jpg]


---
## Installing the Electronic Box

Mounting the electronics box is really easy. Pick a side of the frame to be the "back".
Be sure to check the orientation of the panel mount switch - it only installs one way. If
you're doing multiple panels, you'll want to choose the same "back" on each one so 
the switches all face the same way.

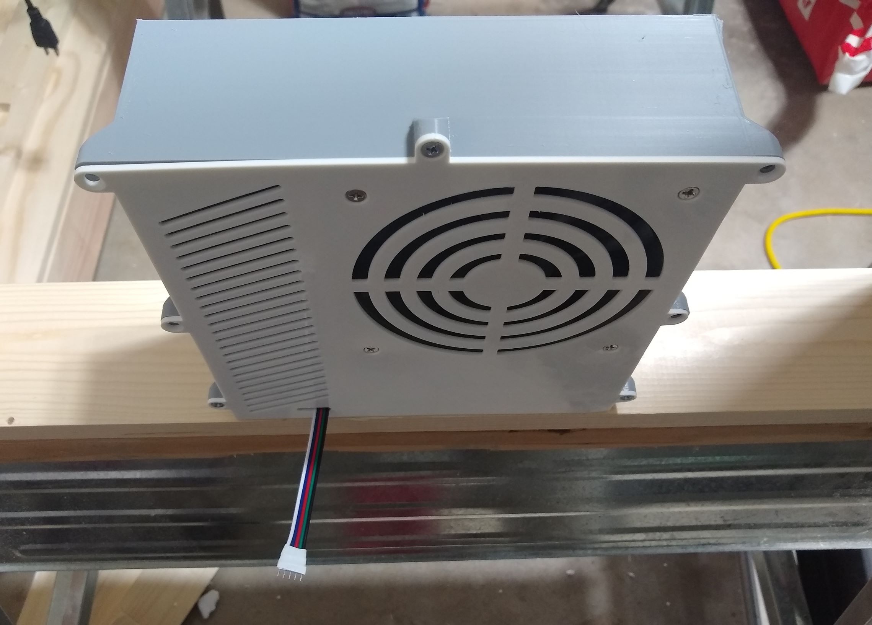
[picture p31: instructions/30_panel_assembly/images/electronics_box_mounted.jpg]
box mounted


Line the box up flush with the side you've chosen as the "back" and screw it down
with four 3/4 inch #6 construction screws, two per side. Pilot holes are not 
needed since the wood is so soft. Don't worry about getting the electronics
enclosure placed precisely in the center along the 24" board. You'll score and
cut each batt of Rockwool inslulation custom to each frame to ensure
a perfect fit. A visual estimate of center is sufficient.

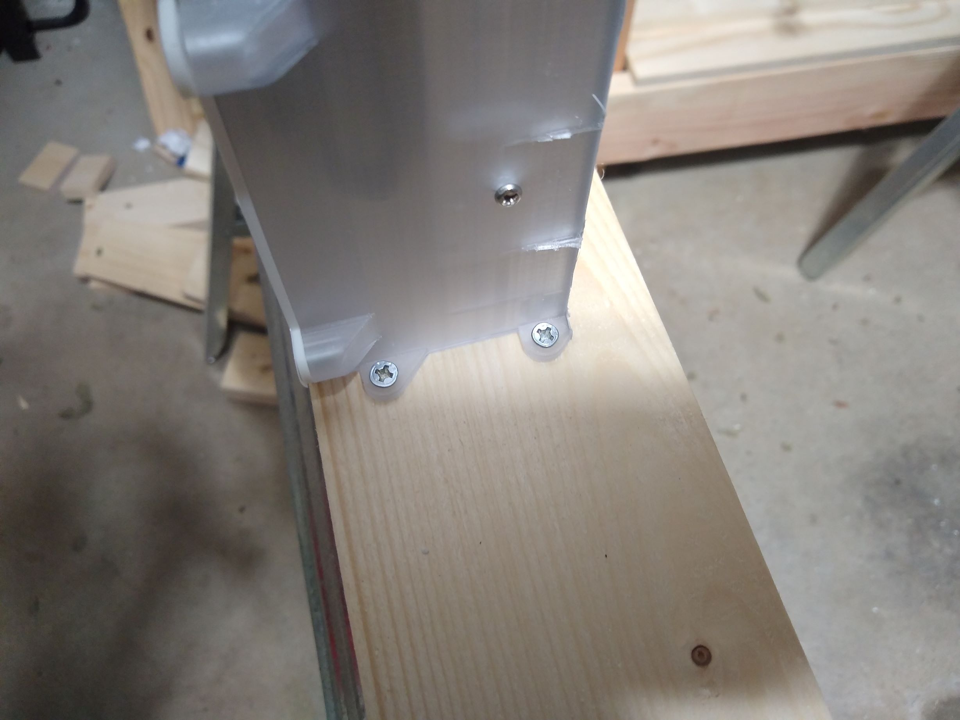
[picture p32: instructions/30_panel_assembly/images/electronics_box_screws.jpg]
screws


---
## Fitting the RockWool

Begin by laying the panel face up, with the electronics access door facing the floor.

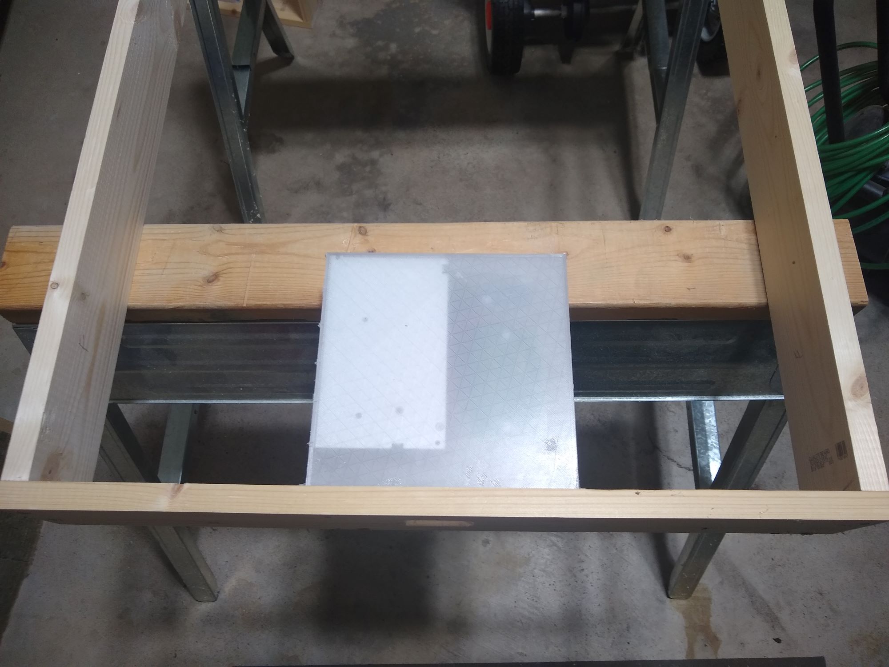
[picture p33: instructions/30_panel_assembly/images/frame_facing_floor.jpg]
frame facing floor


Place a batt of rockwool on top of the frame, leaving room to see the electronics box. Make a mark to indicate the right and left sides of the
electronics box (only one of the two marks is indicated below). 
Because rockwool is soft and pliable, accuracy is not critical. 
Careful visual alignment is all that is required to position the lines.

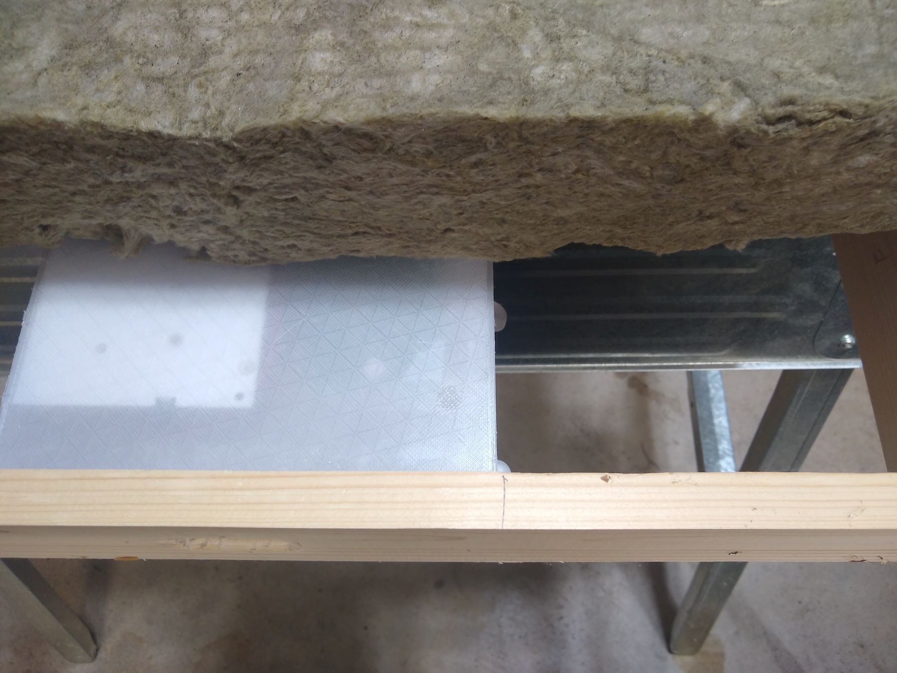
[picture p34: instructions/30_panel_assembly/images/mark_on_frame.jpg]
mark on frame


Using a sharp utility knife and the two marks, score the rockwool batt
in the rough shape of the electronics box. Again, accuracy is not critical.

Once scored, use the utility knife to cut a 2-3 cm thick square of 
rockwool out of the scored area. This square will be used to fill 
the area behind the electronics box cutout.

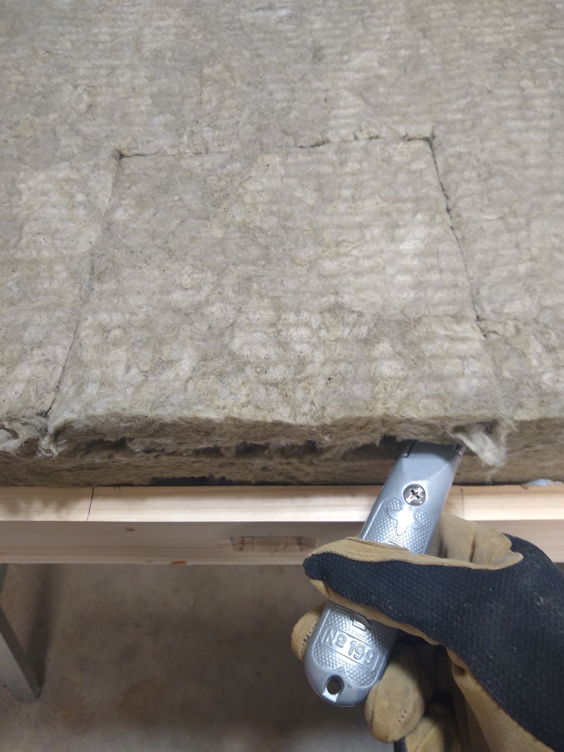
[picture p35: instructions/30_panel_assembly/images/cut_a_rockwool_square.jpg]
cut a rockwool square


You should be left with a nice square of rockwool and a rough
surface cutout approximately the size of the electronics box.

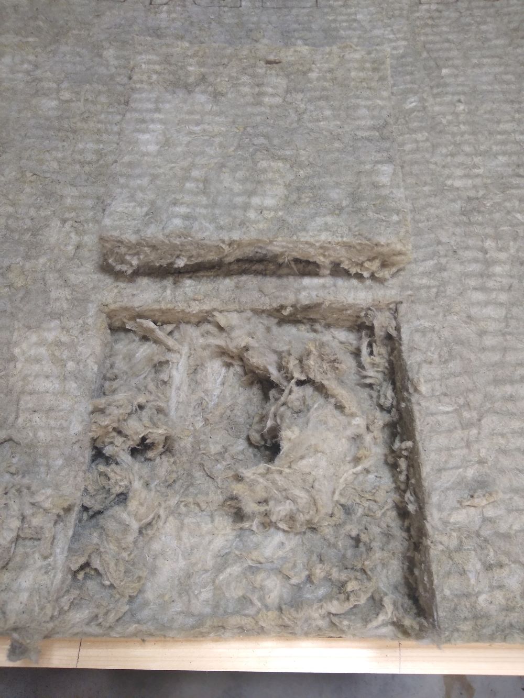
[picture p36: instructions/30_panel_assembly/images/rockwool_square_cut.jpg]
rockwool square cut


Next use a sharp serrated knife or thin saw blade to cut out the rough square
and create a cutout void for the electronics box.

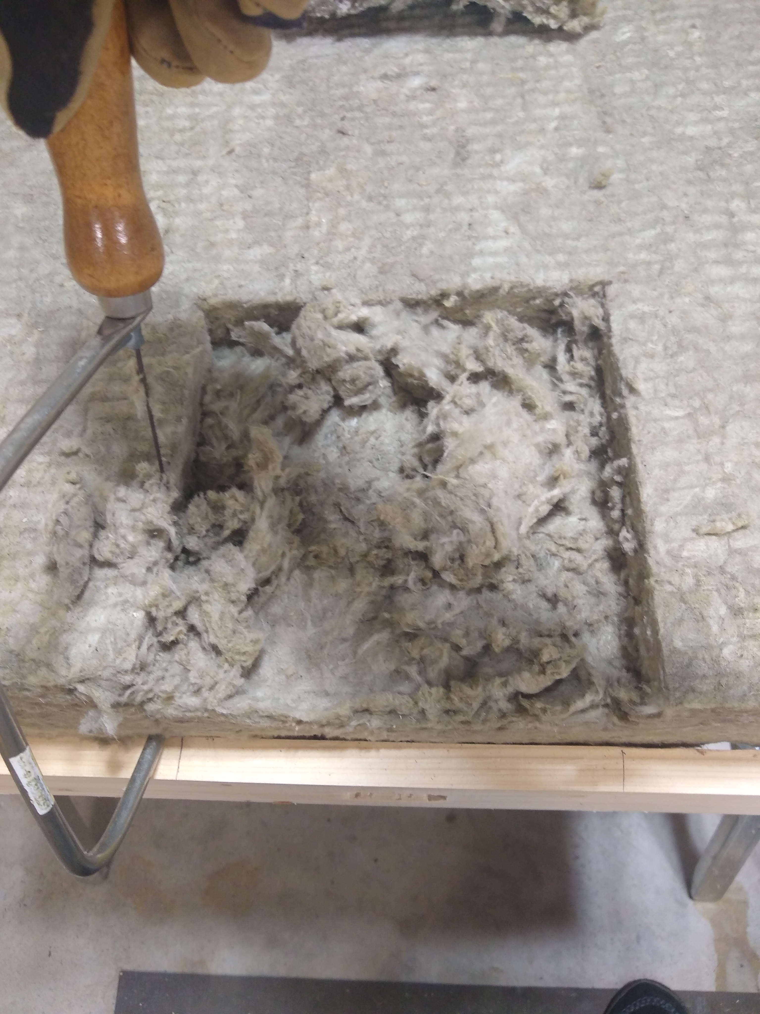
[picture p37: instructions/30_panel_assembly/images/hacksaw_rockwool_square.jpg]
hacksaw rockwool square


You should be left with a nice void and a thin square of rockwool to place
over the electronic box.

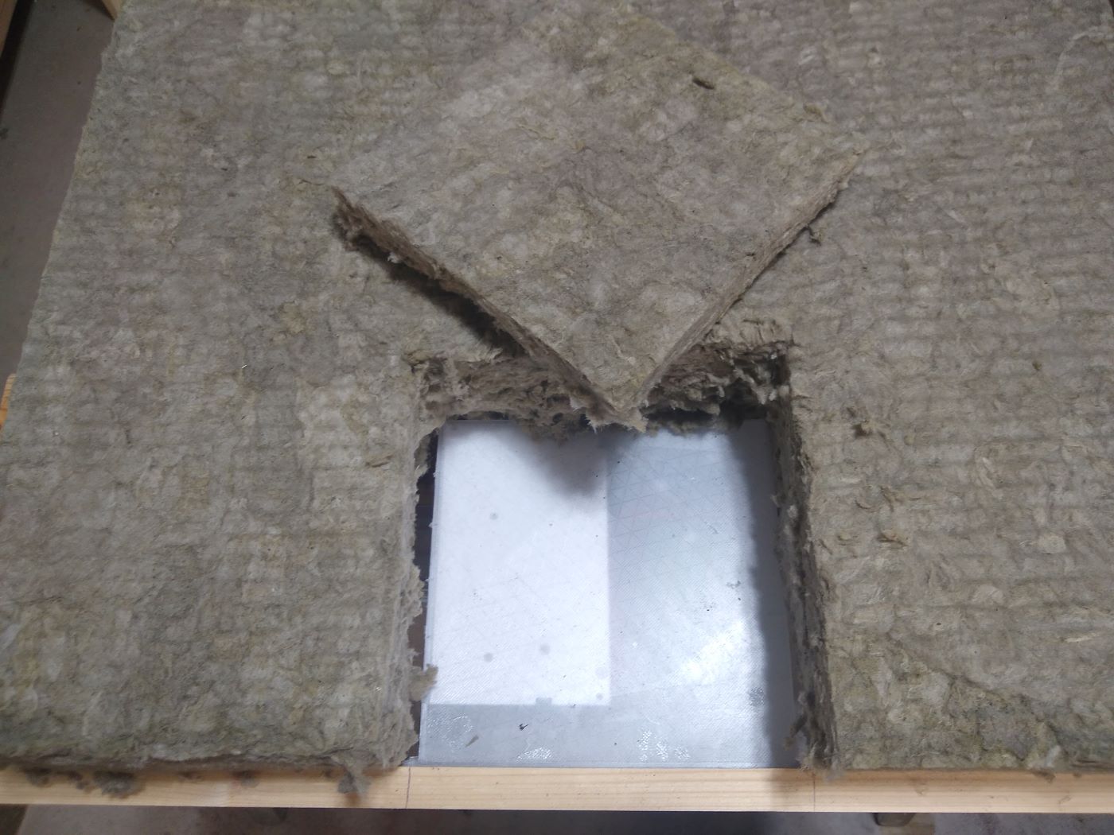
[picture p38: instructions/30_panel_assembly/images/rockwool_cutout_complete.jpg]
rockwool cutout complete


Gently push the rockwool into the frame, then place the square cutout into
the area just over the electronics box. The result should be a nearly 
perfect surface of rockwool. Don't hesitate to peel away or add rockwool 
to achive a consistently flat layer in the area of the electronics box.

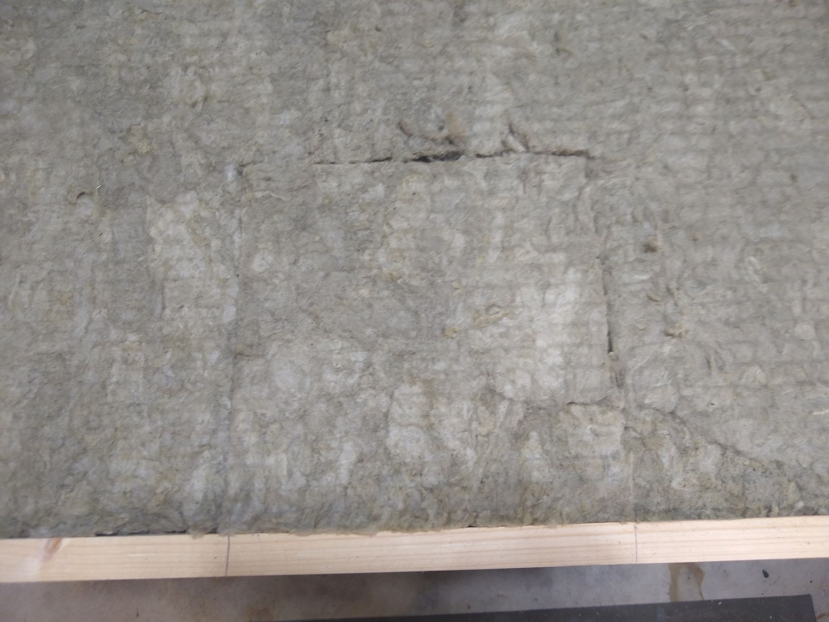
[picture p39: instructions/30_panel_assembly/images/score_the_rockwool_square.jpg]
score the rockwool square


That's it for fitting the rockwool.

## The Front and Back Fabric

Begin by laying the fabric for the front of your panels face 
down on a smooth floor surface. This is a time to think hard, since
making any kind of repair or modification after the fabric is 
stapled on is challenging.

1. Be sure to iron the fabric flat beforehand.
2. Be sure the electronic box is faceing "up" (what will be the back side)
3. Double-check that you like the orientation the switch will be in once mounted.

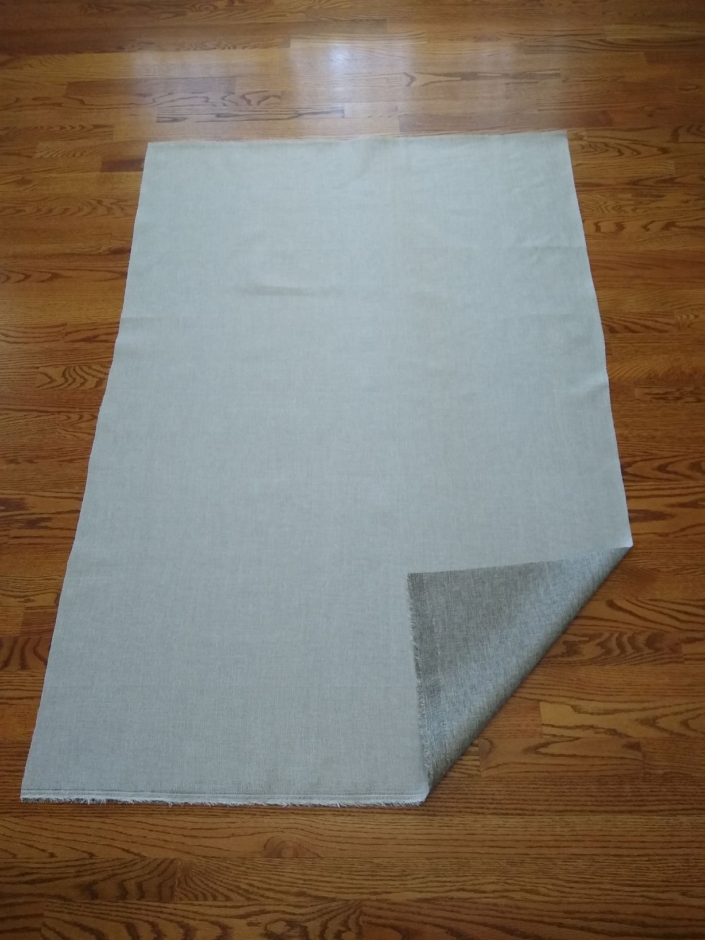
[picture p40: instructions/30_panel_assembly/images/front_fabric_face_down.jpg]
Fabric face down


Lay the rockwool filled frame on the center of that fabric.

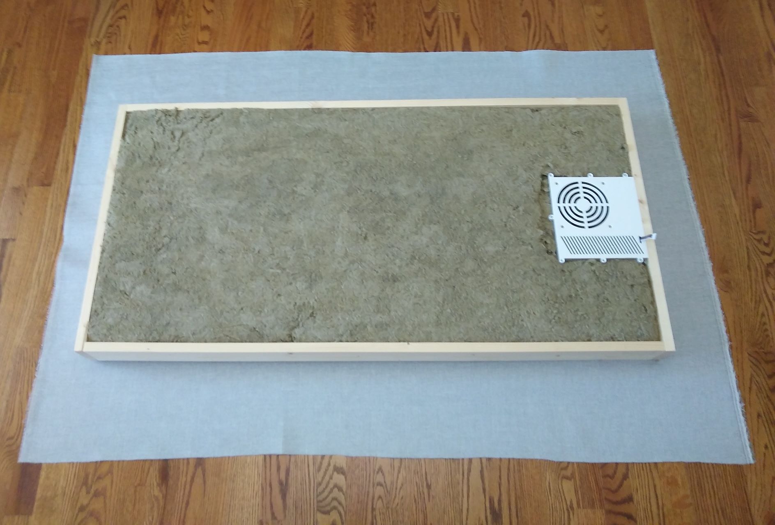
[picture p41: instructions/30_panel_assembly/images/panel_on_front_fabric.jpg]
Panel on Fabric


Then cut the back fabric roughly to size and lay it on top. Don't worry too
much about getting this wrinkle free or centered. It just needs to cover
the back to keep the insulation from falling out the back.

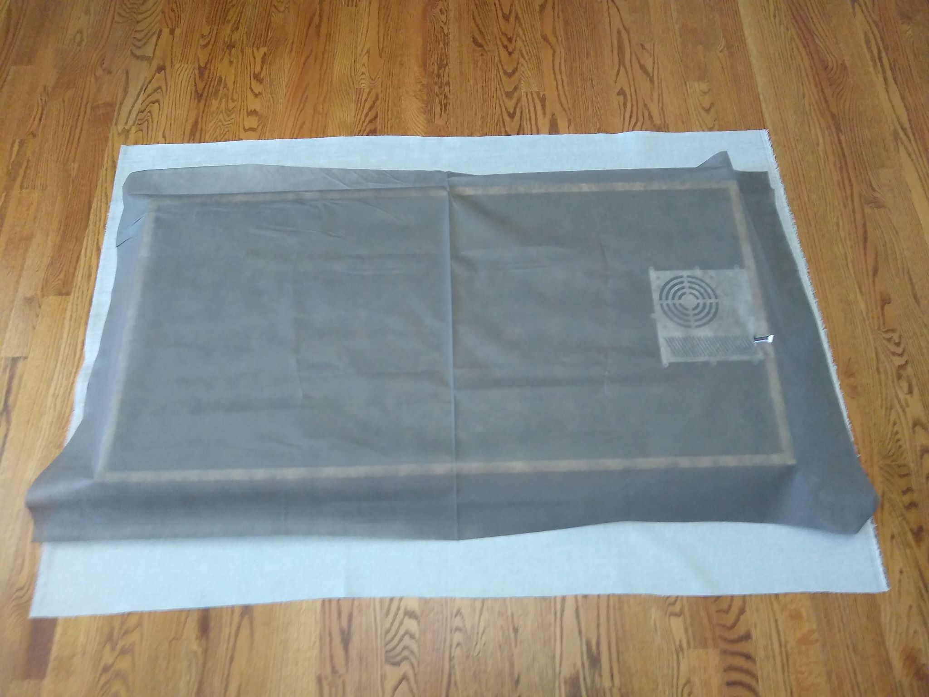
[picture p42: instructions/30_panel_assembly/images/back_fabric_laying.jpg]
back fabric laying


You'll need to cut a small hole in the back fabric to allow the led cable
to pass through.

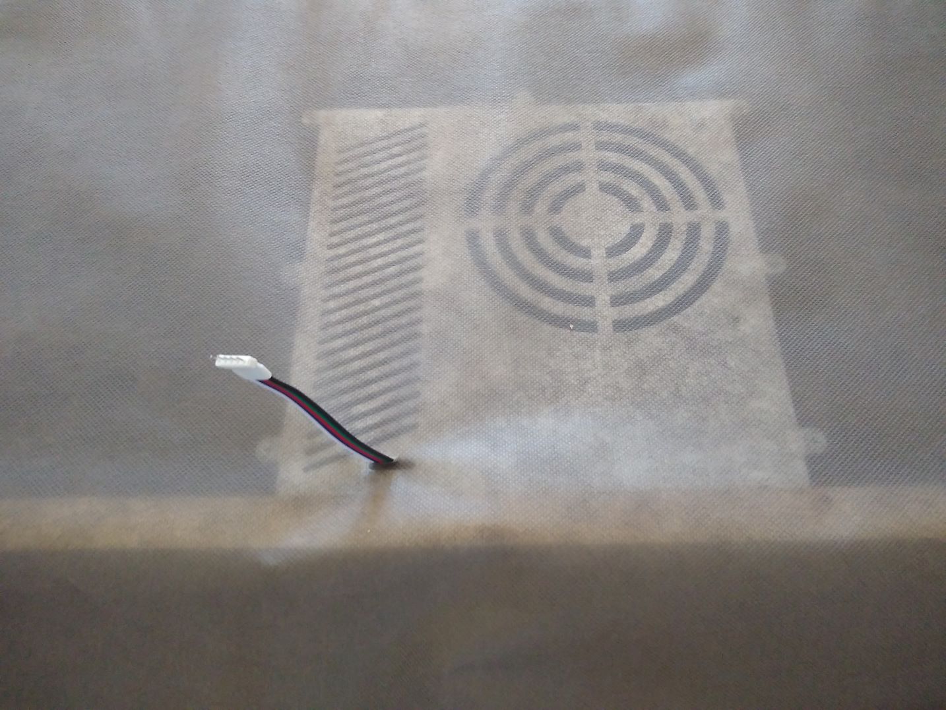
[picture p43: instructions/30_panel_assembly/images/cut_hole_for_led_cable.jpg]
led cable hole


Staple down the back fabric using a stapler, I recommend an Arrow T50 stapler
with 1/4" T50 staples. When it's secure, cut it along the edges to match 
the size of the wooden frame. Fabric shears are a worthy investment
for this purpose. Don't worry about stretching the fabric tight or 
making it wrinkle free. It's not visible when mounted on the wall.

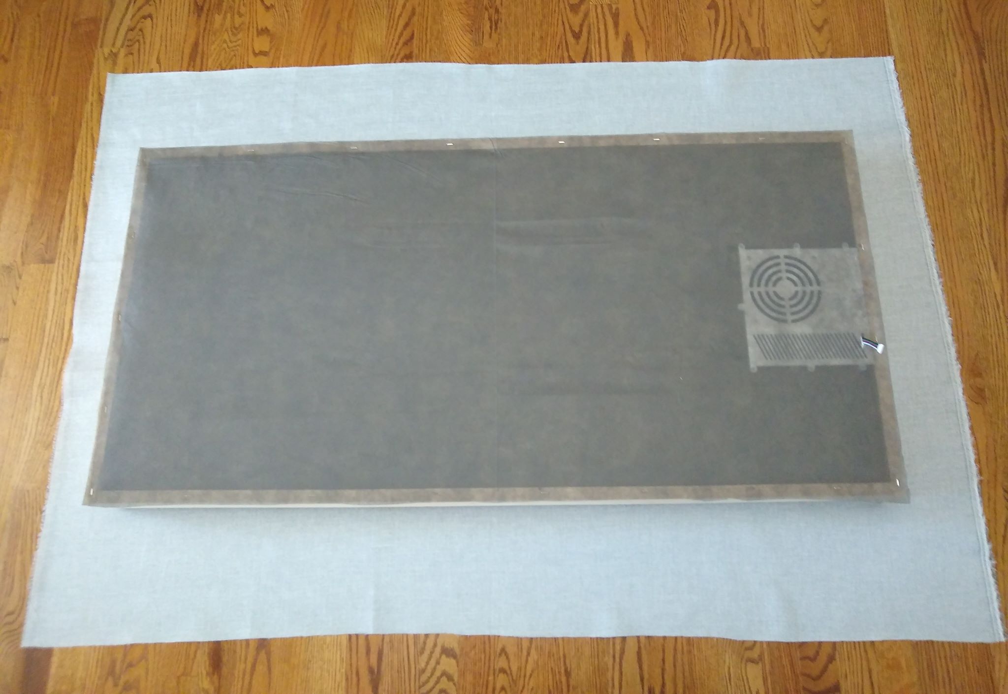
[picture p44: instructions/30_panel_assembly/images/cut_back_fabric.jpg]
Cut Back Fabric


Now it's time to begin stapling the front fabric to the long sides of
the panel frame. I've found it's good to pull the fabric so there's
no slack remaining between the long sides. However I didn't get it
anywhere near "tight" and was very satisfied with the results.

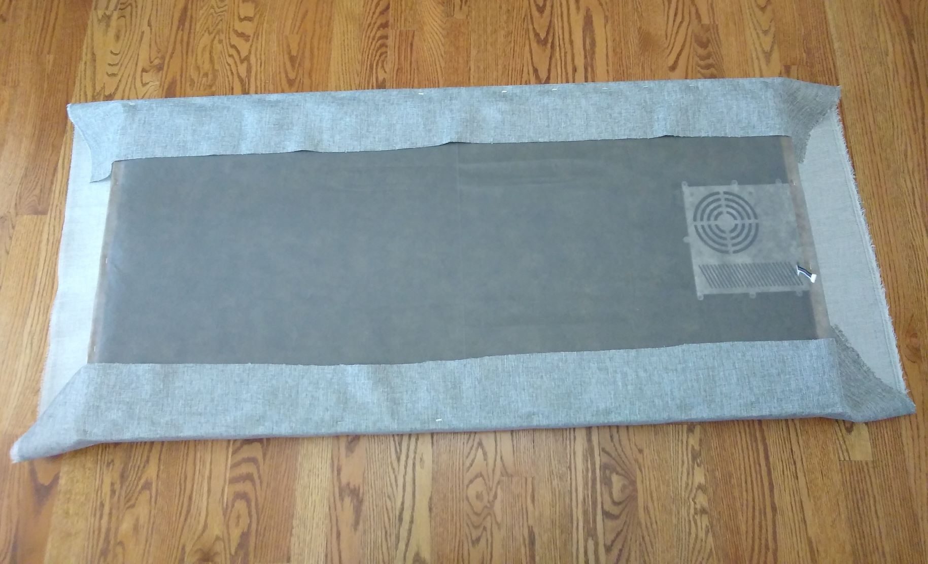
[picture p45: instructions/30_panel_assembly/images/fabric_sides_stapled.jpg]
Fabric sides stapled


## Wrapping the Corners 

By far the most challenging part of wrapping the panels is getting the corners
to look nice. There are many ways to do this, but I'll describe the one I
thought was easy and attractive.

Start by folding the edge like this. You're making a triangle of
folded fabric on the bottom side and another similar triangle on 
the top side. The screwdriver is just in the picture to hold down the
top triangle for visibility in this photo. Feel free to add a
staple or two along the short wooden face to hold the fabric in 
position.

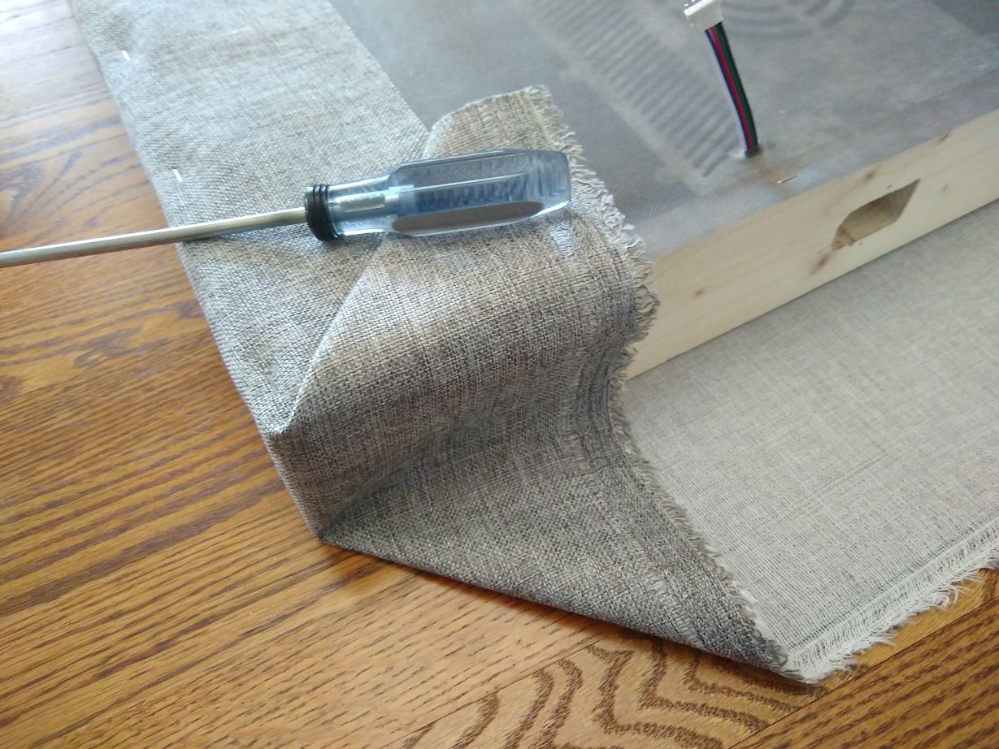
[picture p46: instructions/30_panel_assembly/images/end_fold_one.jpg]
End Fold One


With the screwdriver removed, you'll see how the triangles overlap and 
are similarly sized. This is exactly what you want.

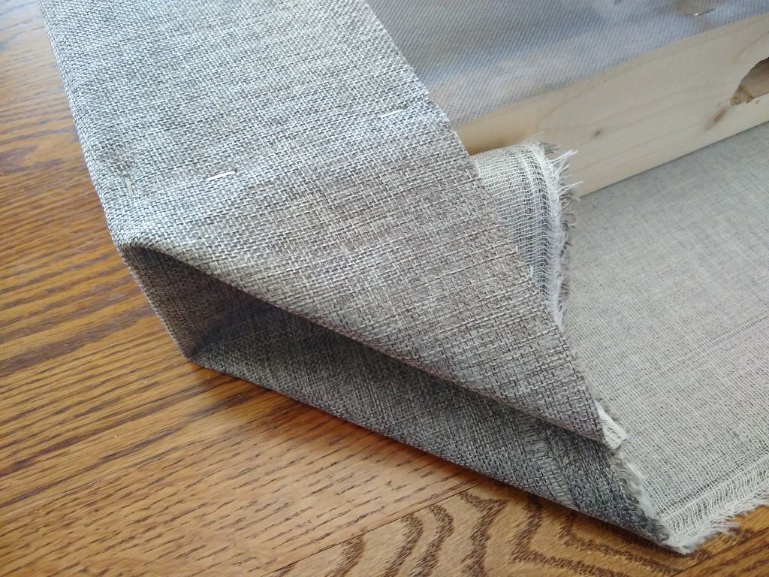
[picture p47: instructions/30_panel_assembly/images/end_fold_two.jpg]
End Fold Two


Cut the point off of the top triangle. You want it to be short enough
to fold over and be stapled flat.

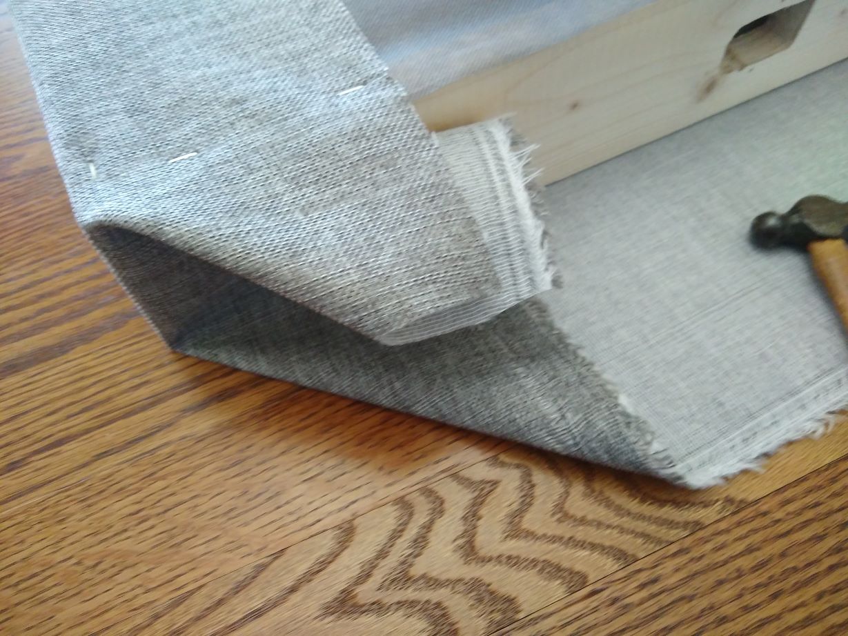
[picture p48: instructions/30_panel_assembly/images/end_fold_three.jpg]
End Fold Three


Once it's cut, go ahead and fold it down and staple it. Try to get
it nice and flat, at a roughly 45 degree angle.

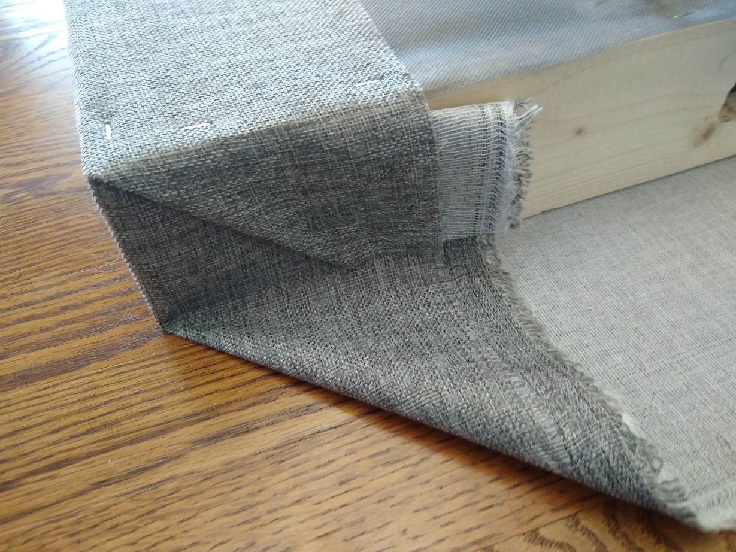
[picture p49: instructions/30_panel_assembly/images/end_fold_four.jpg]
End Fold Four


Now you have a "flap" of fabric to fold up along the short end of the
panel. Repeat the steps above on the other side of the short
end to get the other corner ready to fold, then fold the whole
flap up along the short side of the panel and staple it
well, again aiming fo a roughly 45 degree angle.

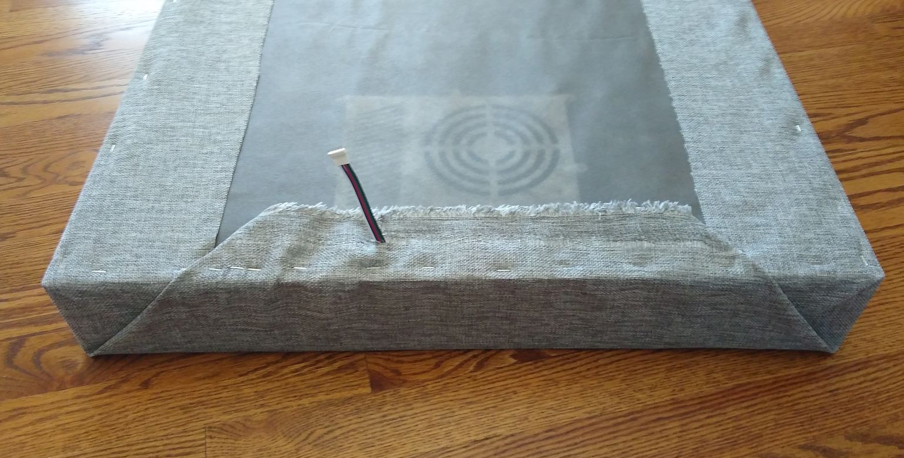
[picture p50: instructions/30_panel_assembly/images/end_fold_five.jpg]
End Fold Five


You may need to cut a small slot in the fabric so the led cable
can exit directly from the back of the electronics enclosure.

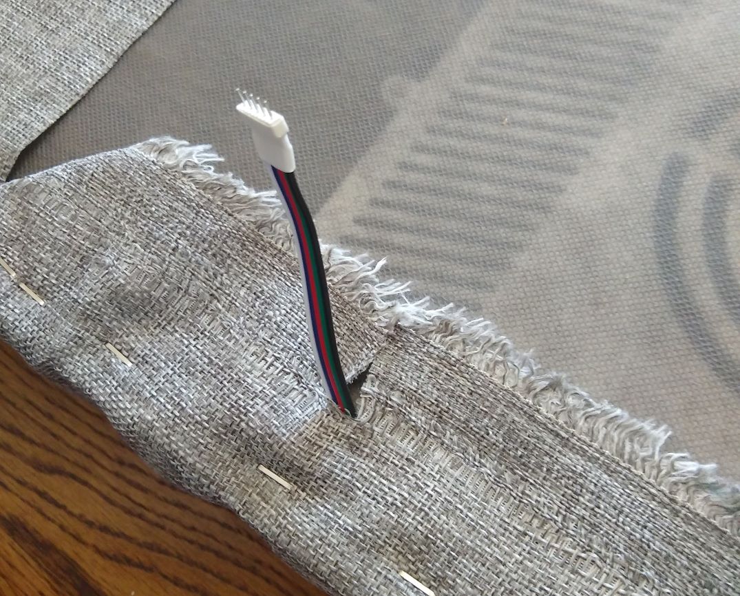
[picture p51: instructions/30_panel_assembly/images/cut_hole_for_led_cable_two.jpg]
led cable hole two


## The Power Switch

Next, you'll need to install the power switch into the hole you routed out.
This will require access to the inside of the electronics box, so use a sharp
blade like a box cutter to cut yourself an access panel into the electronics
box.

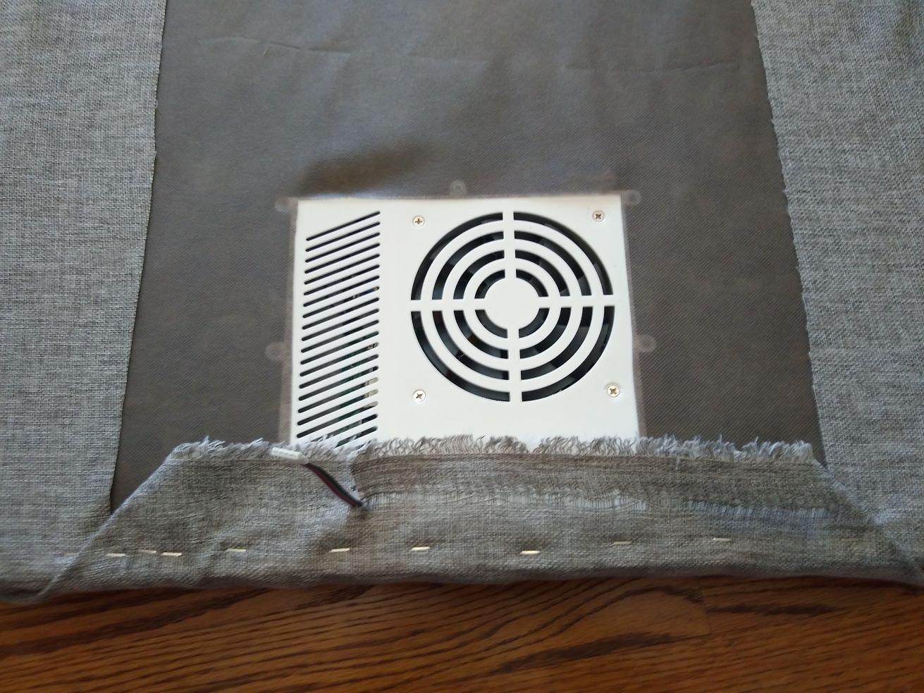
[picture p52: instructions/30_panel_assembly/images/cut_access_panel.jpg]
cut access panel


Remove the screws from the cover plate of the electronic box and open
it up.

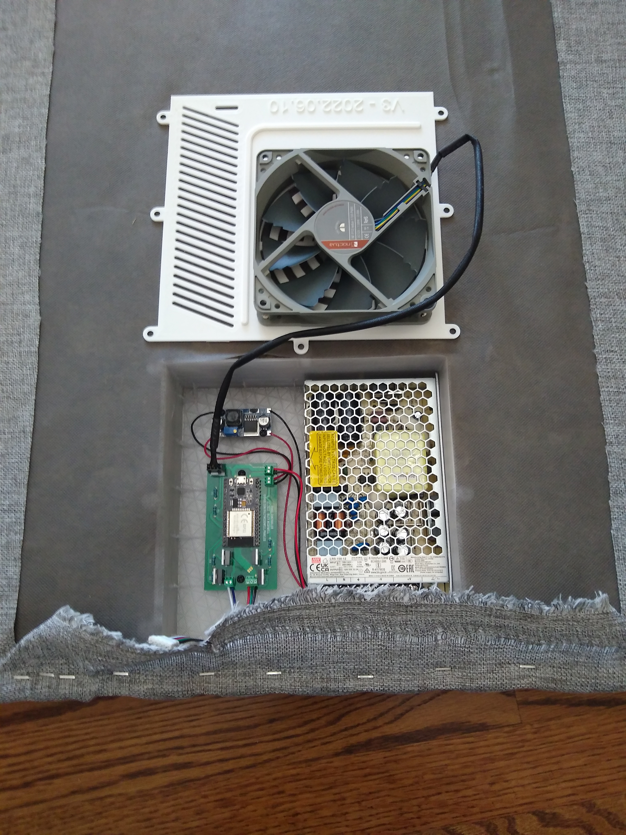
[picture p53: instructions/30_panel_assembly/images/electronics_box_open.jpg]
electronics box open


Cutt an "X" shaped hole in the fabric directly through where
the panel mount switch will go.

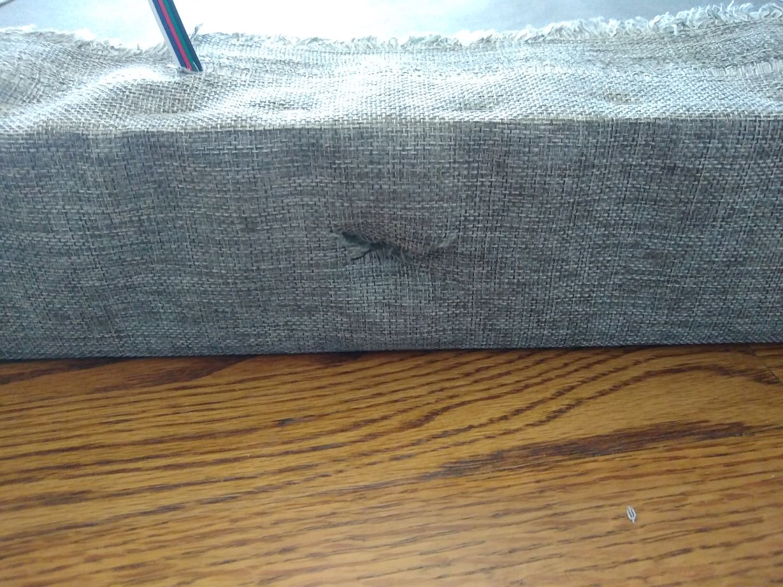
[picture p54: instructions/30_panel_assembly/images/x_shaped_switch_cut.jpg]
x shaped switch cut


Then push the switch in, making sure it's oriented correctly based on the shape
of hole you routed out. Install the two screws that hold it in place.

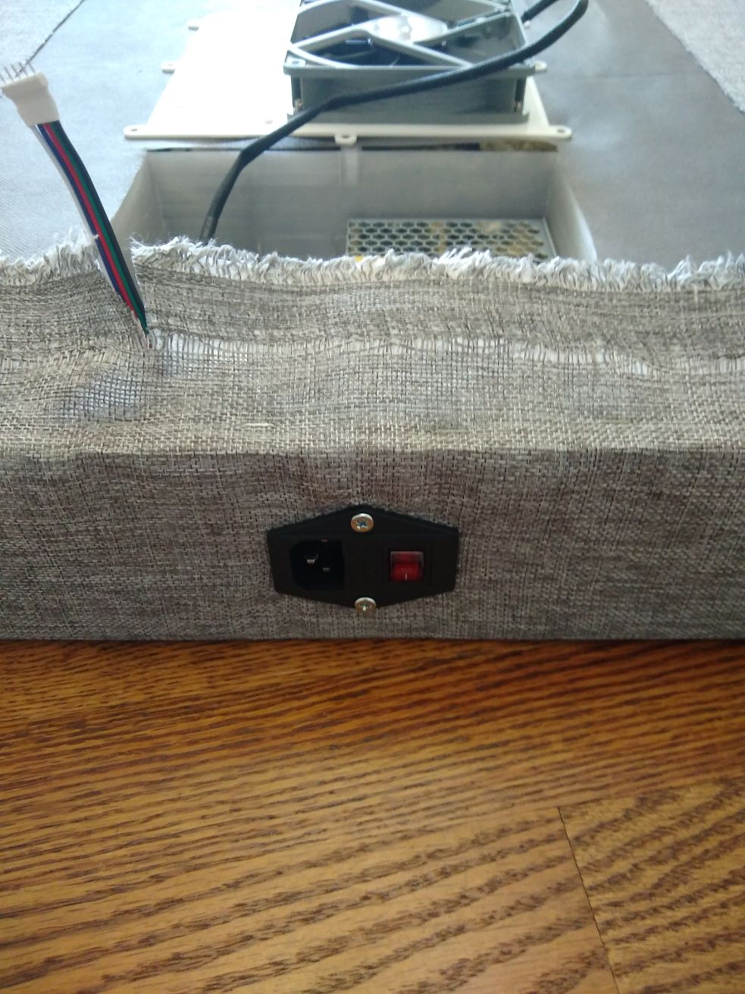
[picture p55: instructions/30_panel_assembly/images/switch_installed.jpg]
switch installed


Then use a Phillips screwdriver to wire the switch to the matching
AC Mains terminals on the power supply.

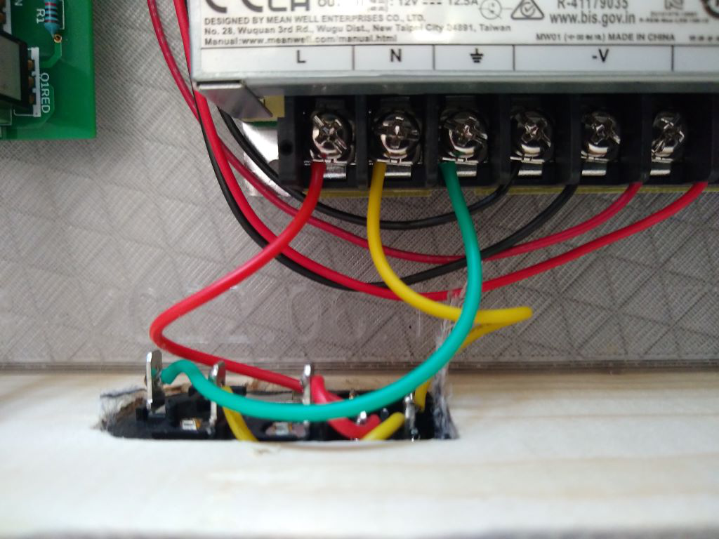
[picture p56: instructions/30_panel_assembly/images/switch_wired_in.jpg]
switch wired in


When you're satisfied with your install, carefully replace and screw down 
the electronics box cover for the last time.

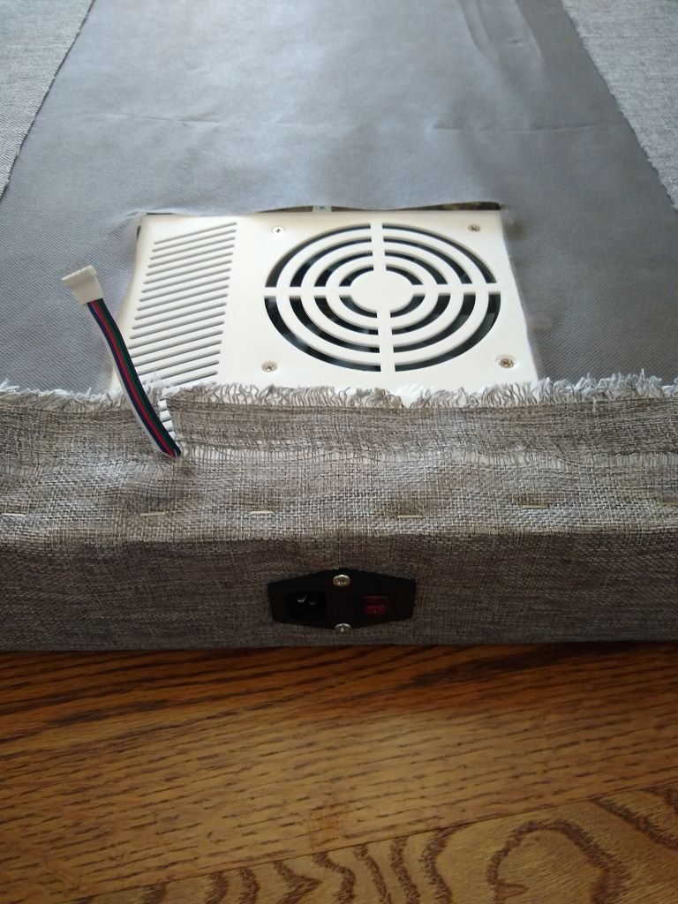
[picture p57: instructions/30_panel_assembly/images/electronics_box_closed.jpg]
electronics box closed


## The LED Strips

Attaching the LED strips is fairly straightforward. Begin by cutting a segment
of strip appropriately sized to align with the output wires from the electronics
box. Leave some room at the left end to place a second short segment.

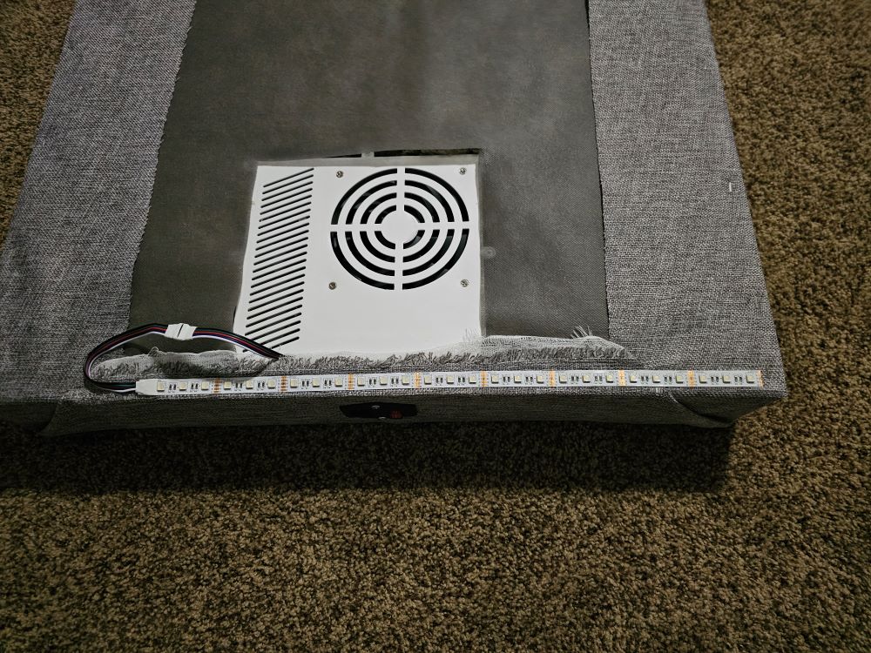
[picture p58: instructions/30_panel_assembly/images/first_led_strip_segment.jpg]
first led strip segment


Go around the back edges of the box applying the LED strip segments 
after cutting to length. Double check each segment for length 
before cutting, and double check each segment for orientation 
before adhering - note the alignment of the 12v contact of 
both strips towards the inside of the panel area in the following 
photo.

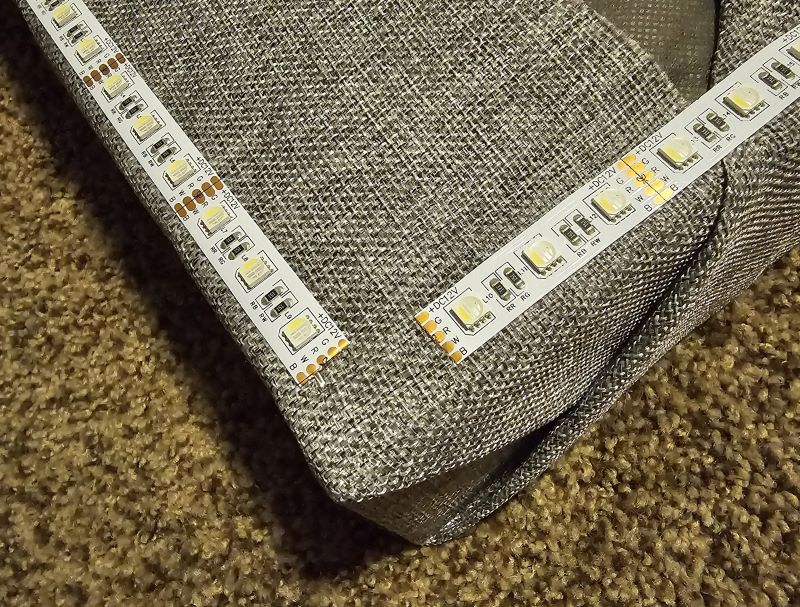
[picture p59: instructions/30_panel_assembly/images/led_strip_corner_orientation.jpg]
led strip corner orientation


When you get back to the corner where you started, apply a smaller strip
to complete the loop and create consistent illumination all around the panel.

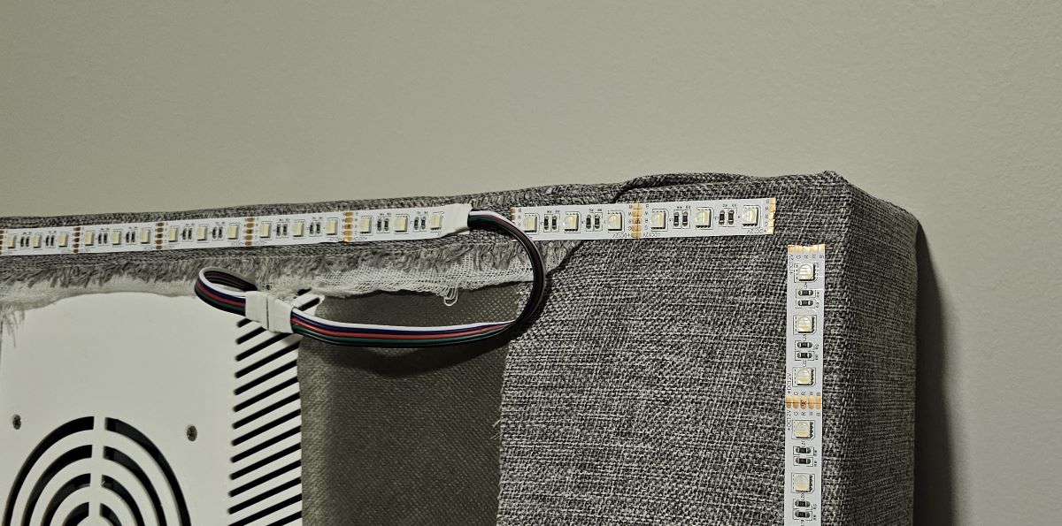
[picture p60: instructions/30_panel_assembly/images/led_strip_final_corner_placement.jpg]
led strip final corner placement


TODO: Soldering

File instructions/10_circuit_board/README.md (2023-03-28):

# Assembling the Custom Circuit Board

## Ordering Boards

There are a lot of options for custom PCB prototyping worldwide. I chose to order from 
[JLCPCB](https://jlcpcb.com) and was extremely impressed with the quality of boards I
received. 

Just drag and drop a copy of the PCB gerber file zip archive from `../../panel_control_pcb` 
into the JLCPCB webpage. I used all the default options except surface finish. For that,
I swapped to the ENIG surface finish for purely cosmetic reasons.

I placing the order and received PCBs less than a week later including overseas shipping.

---
## Ordering Parts

Check the [BoM](../00_bill_of_materials/README.md) for info on the required parts and where to obtain them. 
A combination of Amazon and DigiKey will get you everything you need except the custom PCB itself.

---
## Soldering

I strongly recommend soldering parts onto the PCB in the specific order noted below. When done in 
this order, you can simply set the PCB on a heat-resistant surface (I used a wood table) 
and let gravity hold the pieces in their proper position as you solder each one.

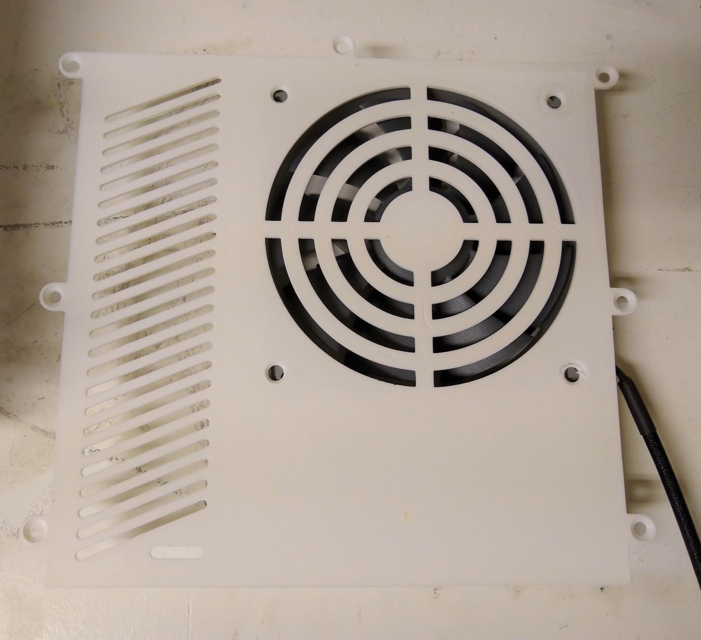
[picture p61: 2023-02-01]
instructions/20_electronics_enclosure/images/lid_fan_installed.jpg

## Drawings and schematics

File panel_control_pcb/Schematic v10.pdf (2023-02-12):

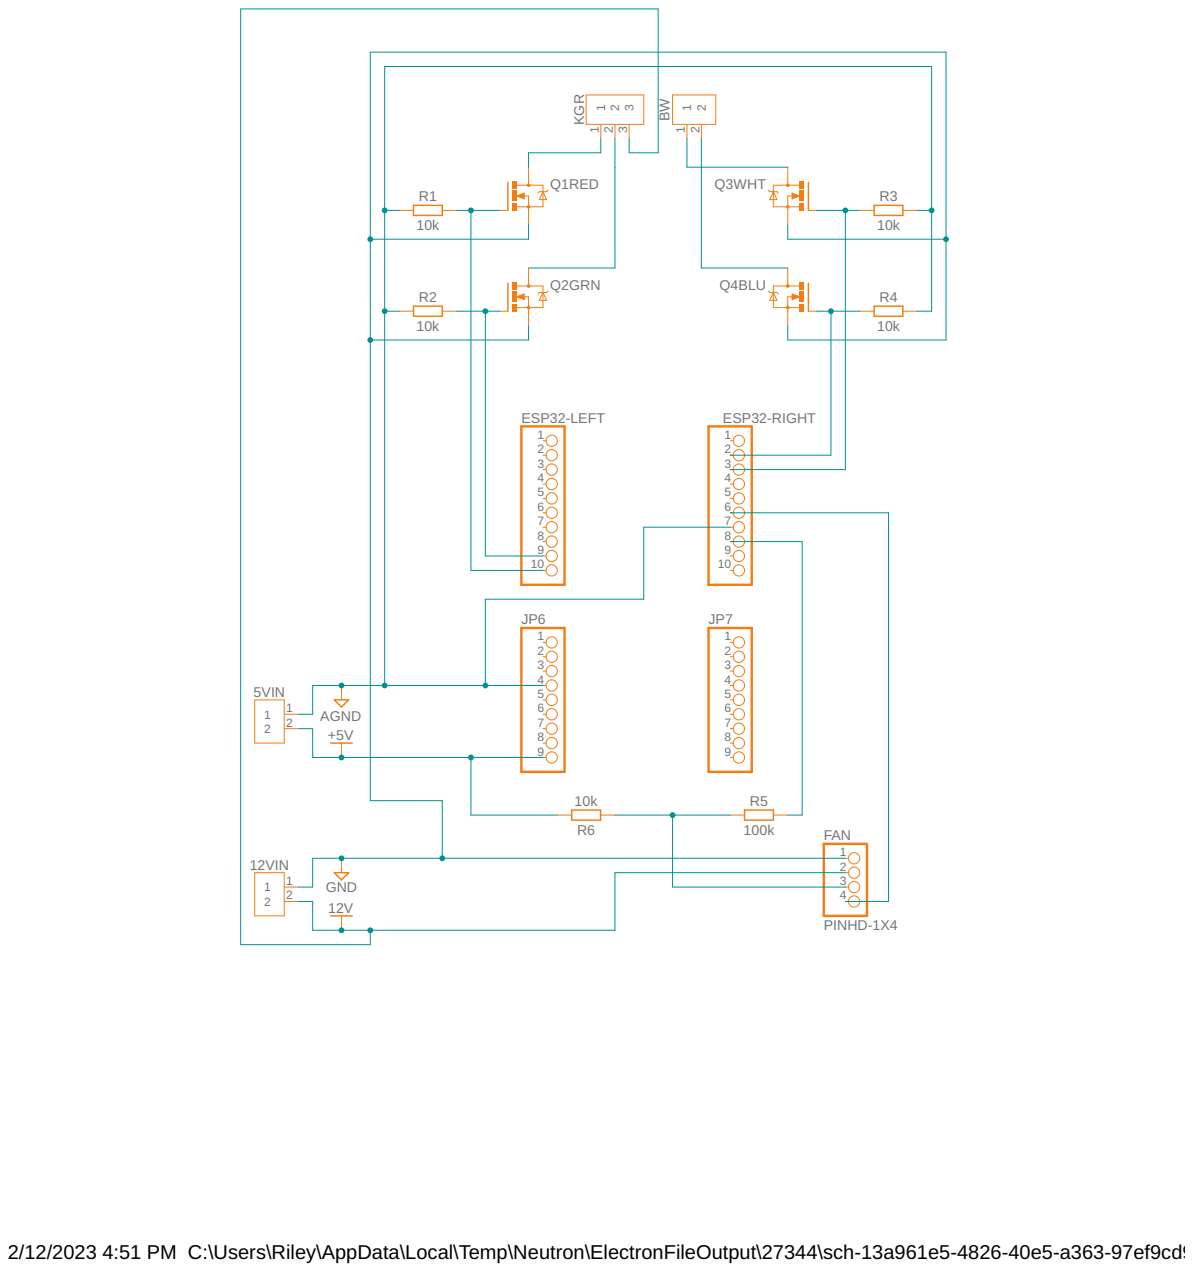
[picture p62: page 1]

2/12/2023 4:51 PM C:\Users\Riley\AppData\Local\Temp\Neutron\ElectronFileOutput\27344\sch-13a961e5-4826-40e5-a363-97ef9cd991eb\Schematic v10.sch (Sheet: 1/1)

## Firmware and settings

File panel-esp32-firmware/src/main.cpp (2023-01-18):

#include "led_control.h"
#include "fan_control.h"
#include "fan_tach.h"
#include "wifi_control.h"
#include "server_control.h"
#include "identification.h"
#include "mdns_control.h"

/* FAN SPEED CONTROL */
const int fanCtrlChannel = 0;
const int fanCtrlPin = 21;
const float fanInitialDutyCycle = 0.3; // 30%
FanControl fanControl = FanControl(fanCtrlChannel, fanCtrlPin, fanInitialDutyCycle);
/* END FAN SPEED CONTROL */

/* FAN TACHOMETER */
const int fanTachometerPin = 19;
FanTach fanTach = FanTach(fanTachometerPin);
/* END FAN TACHOMETER */

/* BEGIN LED PWM */
const int whiteCtrlChannel = 2;
const int whiteCtrlPin = 22;
const float whiteInitialDutyCycle = 0.02;
LedControl whiteControl = LedControl(whiteCtrlChannel, whiteCtrlPin, whiteInitialDutyCycle);

const int redCtrlChannel = 4;
const int redCtrlPin = 26;
const float redInitialDutyCycle = 0.02;
LedControl redControl = LedControl(redCtrlChannel, redCtrlPin, redInitialDutyCycle);

const int greenCtrlChannel = 6;
const int greenCtrlPin = 25;
const float greenInitialDutyCycle = 0.02;
LedControl greenControl = LedControl(greenCtrlChannel, greenCtrlPin, greenInitialDutyCycle);

const int blueCtrlChannel = 8;
const int blueCtrlPin = 23;
const float blueInitialDutyCycle = 0.02;
LedControl blueControl = LedControl(blueCtrlChannel, blueCtrlPin, blueInitialDutyCycle);
/* END LED PWM */

/* BEGIN IDENTIFICATION */
Identification identification = Identification();
/* END IDENTIFICATION */

/* BEGIN WIFI CONTROL */
WifiControl wifiControl = WifiControl(identification);
/* END WIFI CONTROL */

/* BEGIN SERVER CONTROL */
ServerControl serverControl = ServerControl( fanControl
                                           , fanTach
                                           , redControl
                                           , greenControl
                                           , blueControl
                                           , whiteControl
                                           , identification
                                           );
/* END SERVER CONTROL */

/* BEGIN mDNS CONTROL */
MDNSControl mdnsControl = MDNSControl(identification);
/* END mDNS CONTROL */

/* BEGIN SETUP/LOOP CONVENTION */

// the setup function runs once when you press reset or power the board
void setup() {
  Serial.begin(115200);
  fanControl.setupControl();
  fanTach.setupTach();
  whiteControl.setupControl();
  redControl.setupControl();
  greenControl.setupControl();
  blueControl.setupControl();
  identification.setupIdentification();
  wifiControl.setupWifi();
  serverControl.setupServer();
  mdnsControl.setupControl();
}

// the loop function runs over and over again forever
void loop() {
  if (fanTach.hasUpdate()) {
    int rpm = fanTach.getRPM();
    Serial.print("Fan Speed Reported: ");
    Serial.print(rpm);
    Serial.println(" RPM");
  }
  serverControl.handleClient();
}

/* END SETUP/LOOP CONVENTION */
int main() {
  setup();
  while (true) {
    loop();
  }
}

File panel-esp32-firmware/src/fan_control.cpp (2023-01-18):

#include "fan_control.h"
#include <math.h>
#include <esp32-hal-ledc.h>

const int CTRL_FREQ = 25000; // 25 KHz per spec
const int CTRL_RESOLUTION = 8; // 2**8 = 256
const int MAX_DUTY_CYCLE = pow(2, CTRL_RESOLUTION);

FanControl::FanControl(int controlChannel, int controlPin, float initialDutyCyclePct) {
  controlChannel_ = controlChannel;
  controlPin_ = controlPin;
  dutyCycle_ = initialDutyCyclePct * MAX_DUTY_CYCLE;
}

void FanControl::setupControl() {
  // First, setup the PWM frequency and resolution
  ledcSetup(controlChannel_, CTRL_FREQ, CTRL_RESOLUTION); 
  // Then, tell which pin should output that PWM signal.
  ledcAttachPin(controlPin_, controlChannel_);
  // Last, set the initial duty cycle.
  ledcWrite(controlChannel_, dutyCycle_);
}
  
int FanControl::getDutyCycle() {
  return dutyCycle_;
}
  
void FanControl::setDutyCycle(int duty) {
  // Save the value.
  dutyCycle_ = duty;
  // Set the value.
  ledcWrite(controlChannel_, dutyCycle_);
}

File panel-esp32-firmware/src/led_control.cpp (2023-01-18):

#include "led_control.h"
#include <math.h>
#include <esp32-hal-ledc.h>

const int CTRL_FREQ = 20000; // 20 KHz
const int CTRL_RESOLUTION = 10; // 2**10 = 1024
const int MAX_DUTY_CYCLE = pow(2, CTRL_RESOLUTION);

LedControl::LedControl(int ctrlChannel, int ctrlPin, float initialDutyCyclePct) {
  ctrlChannel_ = ctrlChannel;
  ctrlPin_ = ctrlPin;
  dutyCycle_ = initialDutyCyclePct * MAX_DUTY_CYCLE;
}

void LedControl::setupControl() {
  // First, setup the PWM frequency and resolution
  ledcSetup(ctrlChannel_, CTRL_FREQ, CTRL_RESOLUTION); 
  // Then, tell which pin should output that PWM signal.
  ledcAttachPin(ctrlPin_, ctrlChannel_);
  // Last, set the initial duty cycle.
  ledcWrite(ctrlChannel_, dutyCycle_);
}
  
int LedControl::getDutyCycle() {
  return dutyCycle_;
}
  
void LedControl::setDutyCycle(int duty) {
  // Save the value.
  dutyCycle_ = duty;
  // Set the value.
  ledcWrite(ctrlChannel_, dutyCycle_);
}

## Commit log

2023-02-01 more enclosure instructions
2023-02-12 Finished enclosure docs
2023-02-12 pcb docs
    [LED Controller Board v12.f3z]
2023-02-27 BoM part 1
2023-02-27 BoM formatting
2023-03-12 electronics BOM
2023-03-12 Forgot PCB
2023-03-28 panel assembly instructions 1/2 done
2023-04-22 more assembly instructions for panel
2023-05-27 Hotfix - canel service browser to eliminate thread leak
2023-09-16 Describe led strip adhesion
